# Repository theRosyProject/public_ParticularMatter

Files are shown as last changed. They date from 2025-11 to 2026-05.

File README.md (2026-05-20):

# ParticularMatter

ParticularMatter (https://particularmatter.org/) provides air quality monitoring devices built around ESP8266 and ESP32. It measures particulate matter (PM2.5 / PM10) using a PMS5003 sensor, air temperature, relative humidity and atmospheric pressure (T/RH/P) using the Bosch BME280, carbon dioxide (CO2) using the Senseair Sunrise sensor, and reports readings over MQTT.

This repository is the public release — it contains **firmware binaries**, **technical documentation**, and **presentation materials**. No source code is included (yet!).

**3D model (enclosure)** for the EPS8266 device mouting just the PMS5003 sensor:  [ParticulAIR-In 1 on MakerWorld](https://makerworld.com/en/models/1912756-particulair-in-1)

--> Models for the updated ESP32 version are under development.

---

## Repository structure

```
public_ParticularMatter/
├── builds/          # Pre-built firmware binaries and flashing instructions
│   ├── esp32/       # ESP32 firmware (current platform)
│   └── esp8266/     # ESP8266 firmware (legacy platform)
├── slides/          # Presentation and dissemination materials
├── tech-doc/        # Technical documentation (API, firmware internals, types, wiring)
└── LICENSE          # GPL v3
```

---

## Flashing the firmware

### ESP32

Pre-built binaries are in `builds/esp32/`. See [builds/esp32/README.md](builds/esp32/README.md) for full flashing instructions.

Quick start:

```bash
pip install esptool
esptool --chip esp32 --port PORT --baud 921600 write-flash 0x1000 builds/esp32/v1.4.0.bin
```

Replace `PORT` with your serial port (e.g. `/dev/tty.usbserial-0001` on macOS, `COM3` on Windows).

### ESP8266

... add, for compatibility with the legacy device and firmware.

---

## Documentation

Technical documentation lives in [`tech-doc/`](tech-doc/). This includes firmware internals, REST API reference, data types, enums, sensor details, and wiring guides.

---

## License

GPL v3 — see [LICENSE](LICENSE).

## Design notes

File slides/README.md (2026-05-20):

# Slides

Presentation and dissemination materials for the ParticularMatter project.

| File | Event | Date |
|---|---|---|
| `vincent-seminar-29-apr-2026.pdf` | Vincent's seminar at CNR - firmware  | Apr 29, 2026 |
| `ISGlobal_FDallo_pub.pdf` | Fede's seminar at ISGlobal - relevance | Nov 21, 2025 |
| `PM_LorenzoSeminar.pdf` | Lorenzo's seminar at CNR - app overview | Nov 3, 2025 |

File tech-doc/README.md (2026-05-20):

# Tech Doc

If you're looking for documentation on how this project works — firmware, API, types, or wiring — you're in the right place.

This folder covers everything on the technical side of the project. Browse the subfolders based on what you need:

- **`firmware-dev-particularmatter/`** — firmware internals, REST API endpoints, data types, enums, sensor info, and wiring references

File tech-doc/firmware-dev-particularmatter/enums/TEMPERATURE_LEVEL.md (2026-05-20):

# TEMPERATURE_LEVEL

Quality level enum for the `temperature` field in the [`/api/measurements/latest`](../api-docs/endpoints/measurements-latest.md) response.

Thresholds are based on the **ASHRAE 55** thermal comfort zone.

| Value | Color | °C |
| --- | --- | --- |
| `COLD` | 🔵 Blue | < 17 |
| `COOL` | 🟡 Yellow | 17 – 19 |
| `COMFORTABLE` | 🟢 Green | 20 – 26 |
| `WARM` | 🟡 Yellow | 27 – 30 |
| `HOT` | 🔴 Red | > 30 |

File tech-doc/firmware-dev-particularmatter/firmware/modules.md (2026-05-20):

# Firmware Modules

All reusable logic is organized into independent modules under `lib/`. Each module is a self-contained C++ class that is instantiated in `src/main.cpp` and wired together there.

---

## common/

Shared headers used across all modules. Not a class — these are just type and macro definitions.

| File | Description |
| --- | --- |
| `ConnectionState.h` | Enum for Wi-Fi connection states (`CONNECTED`, `CONNECTING`, etc.) |
| `NetworkState.h` | Enum for overall network/MQTT states |
| `Measurement.h` | Shared struct for sensor measurement payloads |
| `API_RESPONSE.h` | Helper functions for serializing uniform HTTP responses |
| `HELPER.h` | General utility macros |
| `LOGGING.h` | `LOGI` / `LOGE` logging macros (wraps `Serial.printf`) |

---

## ESPConfig

Persistent configuration stored in ESP32 NVS (Non-Volatile Storage). Survives reboots and factory resets can be triggered explicitly.

**Responsibilities:**
- Read / write device settings (Wi-Fi SSID/password, AP credentials, MQTT credentials, node ID)
- Provide a `getData()` accessor used by other modules

---

## WiFiManager

Manages the ESP32 Wi-Fi connection in STA mode. Operates asynchronously — call `maintain()` each loop iteration.

**Responsibilities:**
- Connect to a saved SSID
- Track `ConnectionState` (transitions: `DISCONNECTED` → `CONNECTING` → `CONNECTED` / `WRONG_PASSWORD` / `NO_NETWORK_FOUND`)
- Trigger network scan

---

## WebPortal

HTTP web server (port 80) that serves the LittleFS-hosted frontend and exposes the RESTful API. Operates asynchronously — call `maintain()` each loop iteration.

**Responsibilities:**
- Serve static files from LittleFS
- Register and handle all `/api/*` routes
- Drive the node registration flow (HTTPS call to backend, update `ESPConfig`)

See [`docs/api-docs/README.md`](../api-docs/README.md) for the full API reference.

---

## MQTTPublisher

MQTT client that publishes sensor data to the ParticularMatter platform. Operates asynchronously — call `maintain()` each loop iteration.

**Responsibilities:**
- Connect to the MQTT broker using credentials from `ESPConfig` (with 5–60 s exponential reconnect backoff)
- Each cycle, aggregate the latest snapshot from every sensor driver into a single `MeasurementData`
- Publish the aggregate as JSON to `measurements/{node_id}/{sensor_id}` when at least one sensor is valid (per-sensor validity → `null` for failed sensors). See [`docs/notes/mqtt.md`](../notes/mqtt.md) for the full payload schema.
- Forward each published `MeasurementData` to `XTSDStorageDriver::log()` for local CSV logging

---

## PMS5003Driver

Driver for the Plantower PMS5003 particulate matter sensor. Communicates over UART (RX pin 13).

**Responsibilities:**
- Parse binary data frames from the sensor
- Provide PM1.0, PM2.5, PM10 readings
- Non-blocking polling via `poll()`

---

## SenseAirCO2

Driver for the Senseair S8 CO2 sensor. Communicates over I2C.

**Responsibilities:**
- Request and parse CO2 concentration readings
- Non-blocking polling via `poll()`

---

## BME280Driver

Driver for the Bosch BME280 environmental sensor. Communicates over I2C.

**Responsibilities:**
- Read temperature, relative humidity, and barometric pressure
- Wraps the Adafruit BME280 library

---

## NEO6MGPSDriver

Driver for the u-blox NEO-6M GPS module. Communicates over UART1 (RX pin 14, TX pin 27, 9600 baud).

> ⚠️ Do **not** use GPIO 12 — it is the MTDI strapping pin, and GPS TX idles HIGH which forces the ESP32 to boot at 1.8 V flash voltage and bricks uploads.

**Responsibilities:**
- Parse NMEA sentences with TinyGPSPlus
- Provide latitude, longitude, altitude, HDOP, satellite count, and fix status
- Provide an ISO-8601 UTC `datetime` string when both GPS date and time are valid (used by MQTT payload and SD log filenames)

---

## XTSDStorageDriver

Driver for MicroSD card storage over VSPI (CS pin 33). Writes a CSV row per measurement, with daily file rotation and hot-plug support.

**Responsibilities:**
- Mount the SD card (`SD.begin()` with CARD_NONE detection); reinitialise every 3 s when removed
- Rotate log files daily: filename is `/YYYY-MM-DD_log.csv`, derived from the GPS UTC `datetime` of the row being written
- Use `/unknown_log.csv` as a fallback until GPS provides a valid time fix
- Lazily reopen the file as needed; on rotation, sniff the existing first line and append a header marker if the schema doesn't match (FAT cannot prepend)
- Detect I/O failures (card pulled mid-write) → `SD.end()` and schedule a 3 s reinit retry, so the next measurement triggers a fresh open + header check
- Write per-sensor invalid fields as **empty** values (not zeros), keeping partial readings unambiguous

**CSV columns:**

```
datetime,ts_ms,pm1,pm25,pm10,co2,temperature,humidity,pressure,lat,lng,altitude,hdop,satellites,gps_valid
```

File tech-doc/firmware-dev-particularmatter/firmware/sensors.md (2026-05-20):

# Sensors and Wiring

Board: Adafruit ESP32 Feather (HUZZAH32).

| Sensor | Interface | Pins |
| --- | --- | --- |
| PMS5003 | UART | RX = 13 |
| SenseAir S8 | I²C | SDA = 23, SCL = 22, address `0x68` |
| BME280 | I²C | SDA = 23, SCL = 22, address `0x76`/`0x77` |
| NEO-6M GPS  | UART | RX = 14, TX = 27 |
| MicroSD | SPI | CS = 33, SCK = 18, MOSI = 23, MISO = 19 |

## Power

- PMS5003: 5 V
- SenseAir S8: 5 V
- BME280: 3.3 V (or 5 V on Adafruit breakout)
- NEO-6M GPS: 3.3 V or 5 V
- MicroSD: 3.3 V

## Notes

- PMS5003 baud rate: 9600.
- NEO-6M baud rate: 9600.
- BME280 driver auto-detects between `0x76` and `0x77`.
- GPIO 12 is reserved (boot strapping pin) — don't use it.

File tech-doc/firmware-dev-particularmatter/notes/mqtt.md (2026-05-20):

# MQTT Format

## Topic

```
measurements/{node_id}/{sensor_id}
```

`node_id` and `sensor_id` come from pairing ([`POST /api/node/save`](../api-docs/endpoints/node-save.md)).

## Publish

- Interval: 5 seconds
- QoS: 0
- Retain: true
- Sent only after pairing is complete and at least one sensor has a valid reading.

## Payload

```json
{
  "measurement": {
    "pm1": 12,
    "pm25": 18,
    "pm10": 25,
    "co2": 493,
    "temperature": 24.50,
    "humidity": 55.20,
    "pressure": 1013.10,
    "gps": {
      "lat": 44.523474,
      "lng": 11.337641,
      "alt": 35.2,
      "hdop": 1.20,
      "sats": 7,
      "fix": 1
    }
  },
  "validity": { "pm": true, "co2": true, "env": true, "gps": true },
  "datetime": "2026-05-12T14:02:42Z",
  "ts_ms": 87234
}
```

## Fields

| Field | Type | Unit / Meaning |
| --- | --- | --- |
| `measurement.pm1` | `number \| null` | PM1.0, μg/m³ |
| `measurement.pm25` | `number \| null` | PM2.5, μg/m³ |
| `measurement.pm10` | `number \| null` | PM10, μg/m³ |
| `measurement.co2` | `number \| null` | CO₂, ppm |
| `measurement.temperature` | `number \| null` | °C |
| `measurement.humidity` | `number \| null` | %RH |
| `measurement.pressure` | `number \| null` | hPa |
| `measurement.gps.lat` | `number \| null` | latitude, degrees |
| `measurement.gps.lng` | `number \| null` | longitude, degrees |
| `measurement.gps.alt` | `number \| null` | altitude, m |
| `measurement.gps.hdop` | `number \| null` | horizontal dilution of precision |
| `measurement.gps.sats` | `number \| null` | satellites in fix |
| `measurement.gps.fix` | `0 \| 1` | 1 if GPS has a fix |
| `validity.pm` | `boolean` | PMS5003 reading valid |
| `validity.co2` | `boolean` | S8 reading valid |
| `validity.env` | `boolean` | BME280 reading valid |
| `validity.gps` | `boolean` | GPS has a fix |
| `datetime` | `string` | GPS UTC, `YYYY-MM-DDTHH:MM:SSZ` (empty if no time) |
| `ts_ms` | `number` | `millis()` since boot |

Invalid sensor fields are `null`. `ts_ms` is uptime in milliseconds, not epoch time.

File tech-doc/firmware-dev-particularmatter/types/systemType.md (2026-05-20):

# systemType

Type definition for the `systemStatus` field in `GET /api/system/status`.

| Field | Type | Description |
| --- | --- | --- |
| `firmwareName` | String | Always `"ParticularMatter-Node"` |
| `firmwareVersion` | String | e.g. `"v2.0.0"` |
| `macAddress` | String | ESP32 MAC address |
| `isPasswordChanged` | Boolean | `false` means the AP password is still at factory default |
| `firmwareSsid` | String | Current AP hotspot SSID |
| `allowedSkipInit` | Boolean | Status of allowing skip initialize the configuration |

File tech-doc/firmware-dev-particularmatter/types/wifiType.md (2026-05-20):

# wifiType

Type definition for the `wifiStatus` field in `GET /api/system/status`.

| Field | Type | Description |
| --- | --- | --- |
| `ssid` | String | Currently connected SSID; empty string when not connected |
| `ipAddress` | String | Device IP address in STA mode; empty string when not connected |
| `macAddress` | String | ESP32 MAC address |
| `rssi` | Number | Signal strength in dBm; `0` when not connected |
| `connectionState` | [CONNECTION_STATE](../enums/CONNECTION_STATE.md) | WiFi connection state |

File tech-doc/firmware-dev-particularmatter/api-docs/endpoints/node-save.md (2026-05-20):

# POST /api/node/save

Pairs the device with the ParticularMatter platform using a one-time key (OTK).

On success, the device receives MQTT credentials and begins publishing sensor data automatically. Poll [`GET /api/system/status`](./system-status.md) to track the `pairingState`.

> **Prerequisite:** The device must have an active WiFi connection (`connectionState === "CONNECTED"`) before calling this endpoint.

## Request

| Field | Value |
| --- | --- |
| URL | `/api/node/save` |
| Method | POST |
| Content-Type | application/json |
| Auth | None |

### Request Body

| Field | Type | Required | Description |
| --- | --- | --- | --- |
| `oneTimeKey` | String | Yes | Time-limited key generated by the ParticularMatter platform |

### Request Example

```json
{
  "oneTimeKey": "OTK-a1b2c3d4e5f6"
}
```

## Response (`data`)

```json
{}
```

## Pairing State Tracking

Pairing is asynchronous. After calling this endpoint, poll `GET /api/system/status` and observe `pairingState`:

| pairingState | Description |
| --- | --- |
| `REGISTERING` | Device is executing the pairing request in the background |
| `REGISTERED` | Pairing successful |
| `INVALID_KEY` | Server returned 400 / 401 / 403 (key invalid or expired) |
| `NETWORK_ERROR` | Server unreachable, timeout, or TLS failure |

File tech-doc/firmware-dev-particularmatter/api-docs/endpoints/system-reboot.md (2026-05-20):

# POST /api/system/reboot

Triggers an ESP32 reboot.

## Request

| Field | Value |
| --- | --- |
| URL | `/api/system/reboot` |
| Method | POST |
| Content-Type | application/json |
| Auth | None |

### Request Body

None.

## Response (`data`)

```json
{}
```

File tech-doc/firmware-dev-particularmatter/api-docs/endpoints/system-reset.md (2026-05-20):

# POST /api/system/reset

Factory resets the ESP32 by clearing all saved settings. The device reboots automatically after the reset completes.

## Request

| Field | Value |
| --- | --- |
| URL | `/api/system/reset` |
| Method | POST |
| Content-Type | application/json |
| Auth | None |

### Request Body

None.

## Response (`data`)

```json
{}
```

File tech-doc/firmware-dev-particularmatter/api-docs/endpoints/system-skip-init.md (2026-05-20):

# POST /api/system/skip-init

Sets `allowedSkipInit` to `true` on the ESP32, allowing the device to skip the initialization step on next boot.

## Request

| Field | Value |
| --- | --- |
| URL | `/api/system/skip-init` |
| Method | POST |
| Content-Type | application/json |
| Auth | None |

### Request Body

None.

## Response (`data`)

```json
{}
```

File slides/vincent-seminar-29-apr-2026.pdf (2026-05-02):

ISP-CNR – Feng Chia University Students' Internship – 29 April 2026

# User-friendly ESP32 firmware application to simplify network configuration for open-source IoT devices

Meng Xian Yang
& Federico Dallo

# The problem – Needs

- Necessary to build new tools (models and data) to estimate
- Indoor exposure to air pollution
- Main causes (activities, building factors, infiltration, etc)
- The results will be used
- to inform target stakeholders (municipalities, building sector, environmental agencies, …)
- to develop specific intervention (e.g., new ERF, greening, enhance air filtration in buildings, …)
→ EU funded project healthRiskADAPT | WP leader ISP-CNR

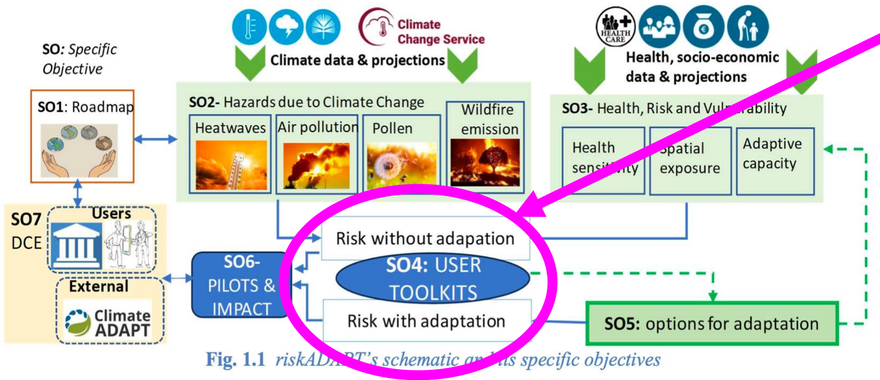
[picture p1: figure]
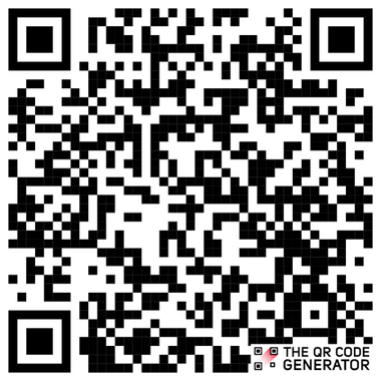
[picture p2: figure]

# The problem – Existing Solution

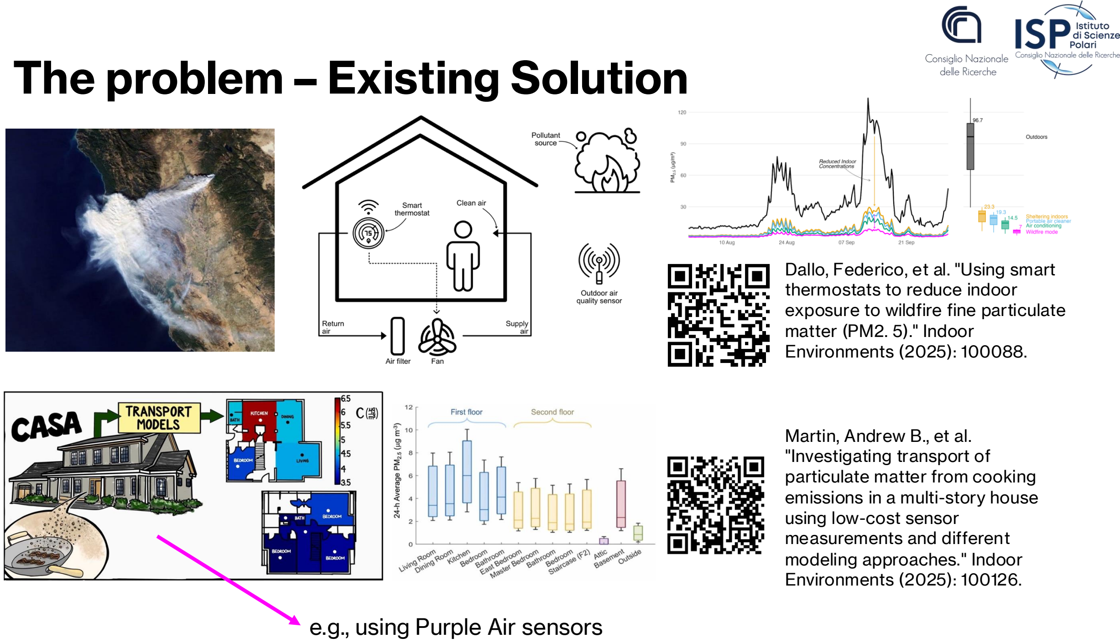
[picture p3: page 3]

Dallo, Federico, et al. "Using smart thermostats to reduce indoor exposure to wildfire fine particulate matter (PM2. 5)." Indoor
Environments (2025): 100088.

Martin, Andrew B., et al.
"Investigating transport of particulate matter from cooking emissions in a multi-story house using low-cost sensor
measurements and different modeling approaches." Indoor Environments (2025): 100126.

e.g., using Purple Air sensors

# Locations & Sensors Management

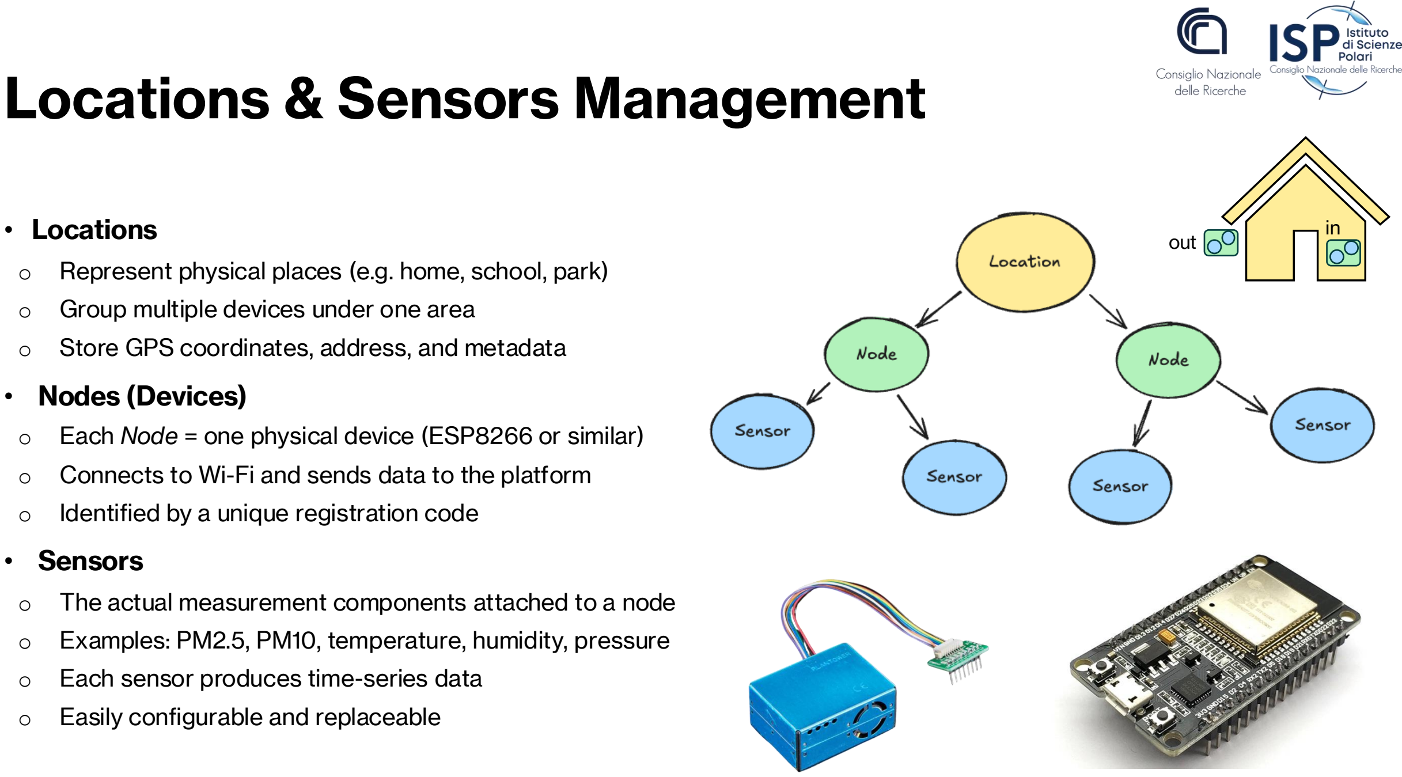
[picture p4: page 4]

- Locations
- Represent physical places (e.g. home, school, park)
- Group multiple devices under one area
- Store GPS coordinates, address, and metadata
- Nodes (Devices)
- Each Node = one physical device (ESP8266 or similar)
- Connects to Wi-Fi and sends data to the platform
- Identified by a unique registration code
- Sensors
- The actual measurement components attached to a node
- Examples: PM2.5, PM10, temperature, humidity, pressure
- Each sensor produces time-series data
- Easily configurable and replaceable

out

in

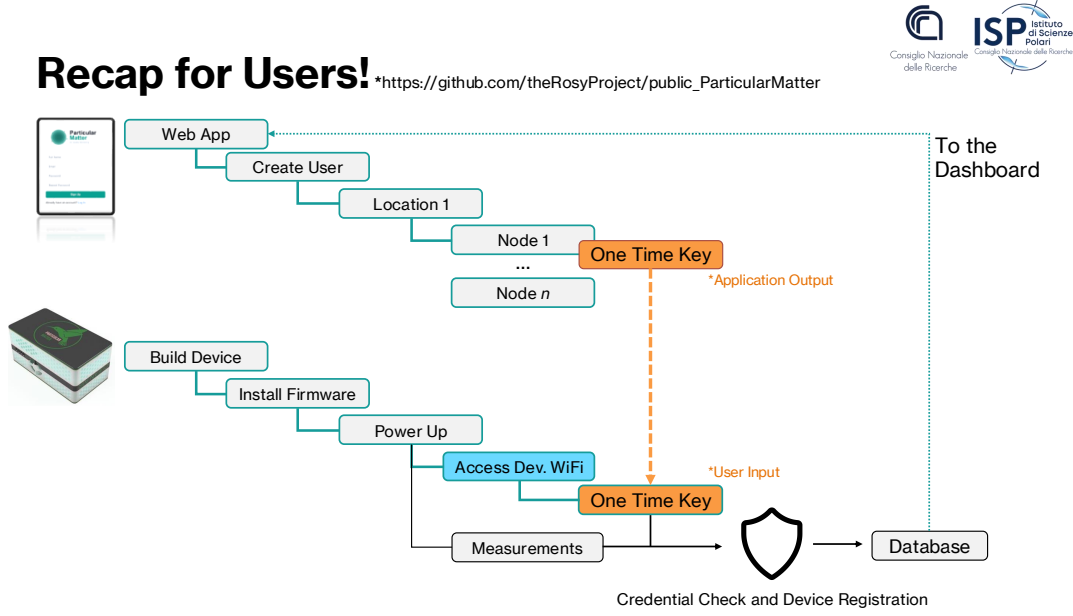
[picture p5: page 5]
Web App; Create User; Location 1; Node 1; Node n; Build Device; Install Firmware; Power Up; Measurements; Database; To the Dashboard; *Application Output; *User Input

Recap for Users! *https://github.com/theRosyProject/public_ParticularMatter

One Time Key

Access Dev. WiFi

Credential Check and Device Registration

ISP-CNR – Feng Chia University Students' Internship – 29 April 2026

# User-friendly ESP32 firmware application to simplify network configuration for open-source IoT devices

Meng Xian Yang
& Federico Dallo

# Introduction – Meng Xian Yang (Vincent)

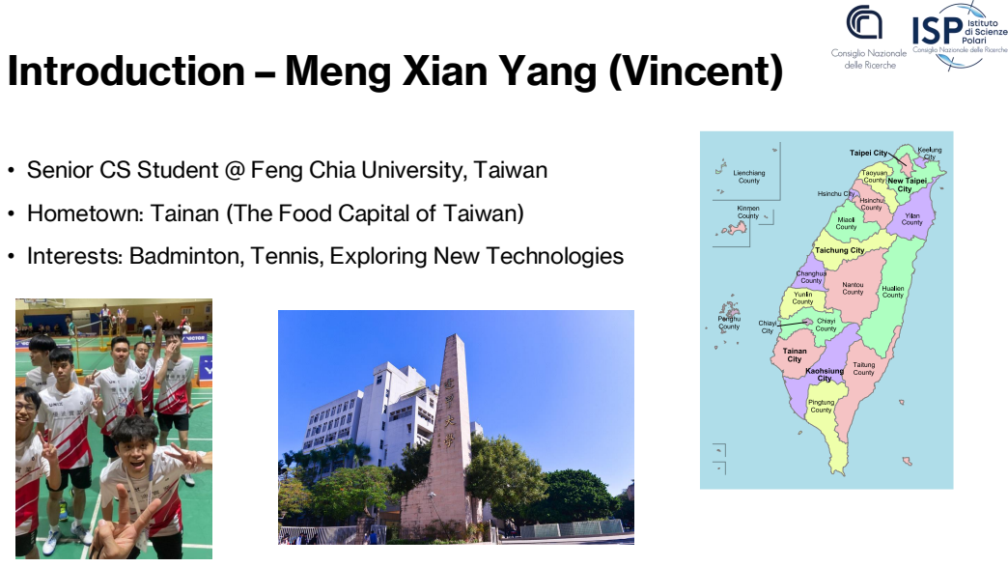
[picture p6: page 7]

• Senior CS Student @ Feng Chia University, Taiwan

• Hometown: Tainan (The Food Capital of Taiwan)

• Interests: Badminton, Tennis, Exploring New Technologies

# My Tech Stack & Background

- 3 Years of Software Development | 1 Year of AI Engineering
- Software Engineering
- Focus: Full-stack Development · System Integration · Cloud Deployment
- Tech Stack: Node.js, NestJS, React, PostgreSQL, Firebase, Docker, GCP, etc.
- AI & Computer Vision
- Focus: Object Detection · Multi-Object Tracking · Model Training
- YOLO, SAM, DeepSORT, etc.

# Earlier Work: 360° Badminton Highlight System

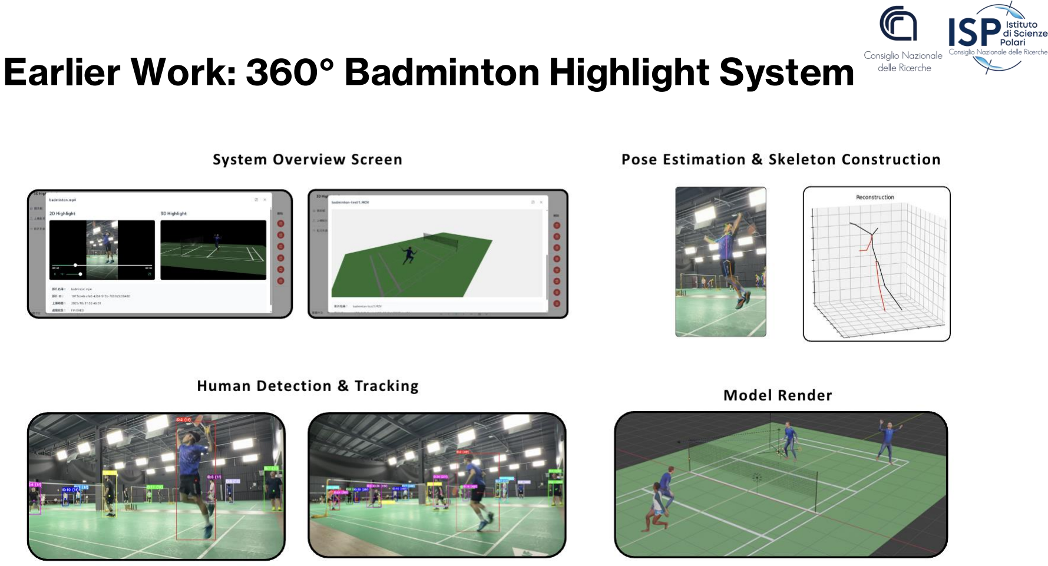
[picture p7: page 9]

# CNR: World-Class Research in a Historic City

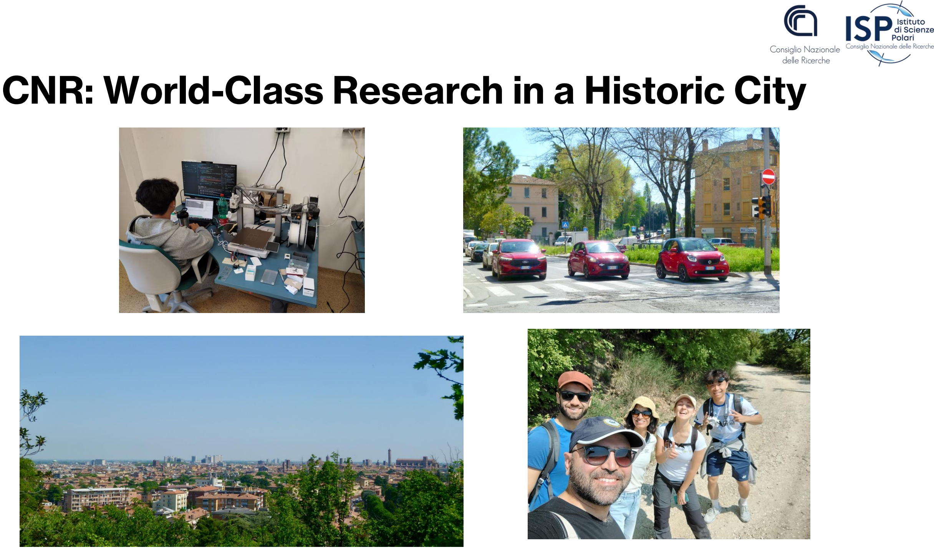
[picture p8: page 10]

# Particular Matter Framework

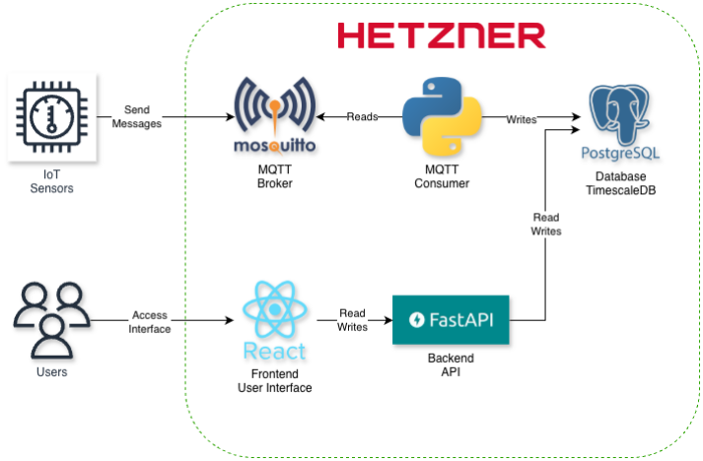
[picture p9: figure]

System Architecture Overview

# The solution – what?

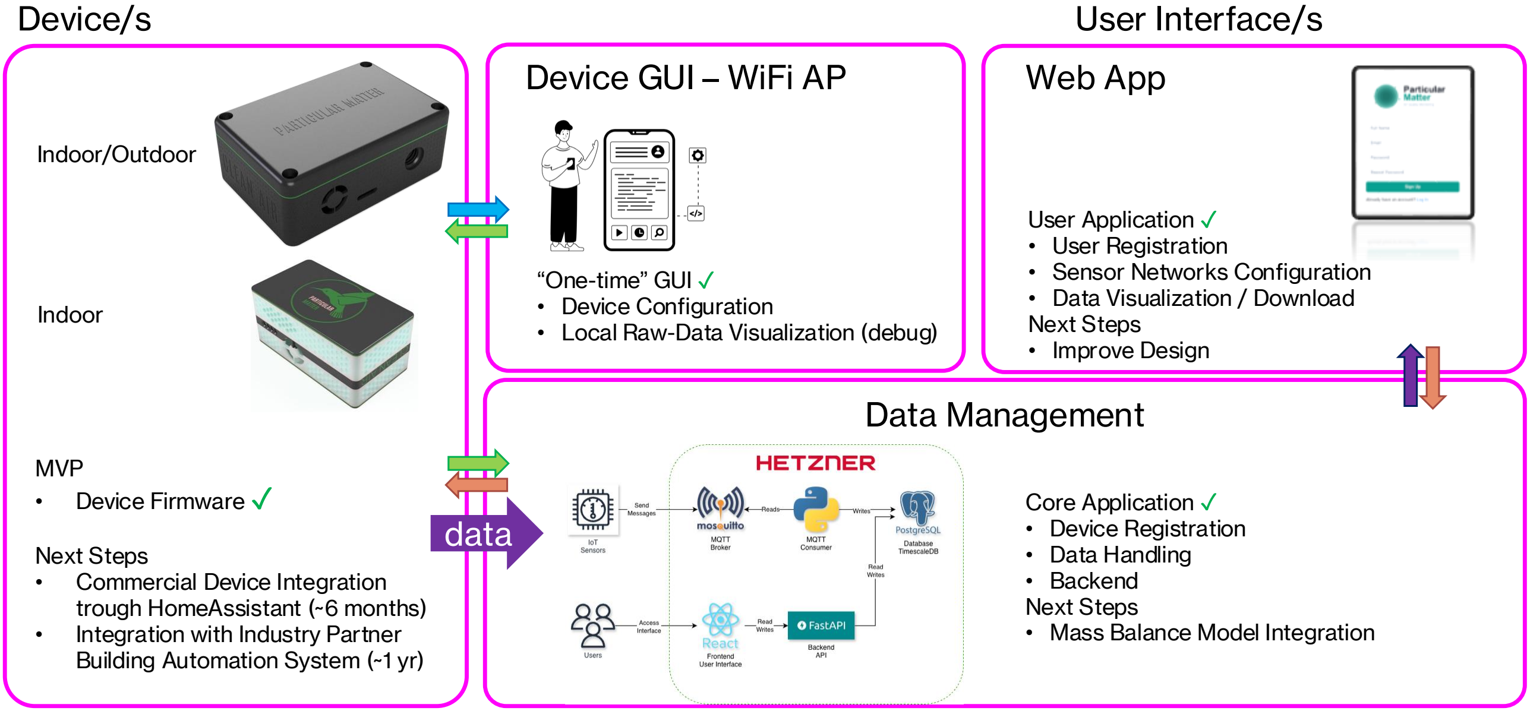
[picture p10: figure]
Device/s; Data Management; User Interface/s; Indoor/Outdoor; Indoor; MVP • Device Firmware ✓; Next Steps • Commercial Device Integration trough HomeAssistant (~6 months) • Integration with Industry Partner Building Automation System (~1 yr); Device GUI – WiFi AP; Web App; “One-time” GUI ✓ • Device Configuration • Local Raw-Data Visualization (debug); User Application ✓ • User Registration • Sensor Networks Configuration • Data Visualization / Download Next Steps • Improve Design; Core Application ✓ • Device Registration • Data Handling • Backend Next Steps • Mass Balance Model Integration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

# DIY Device – Registration

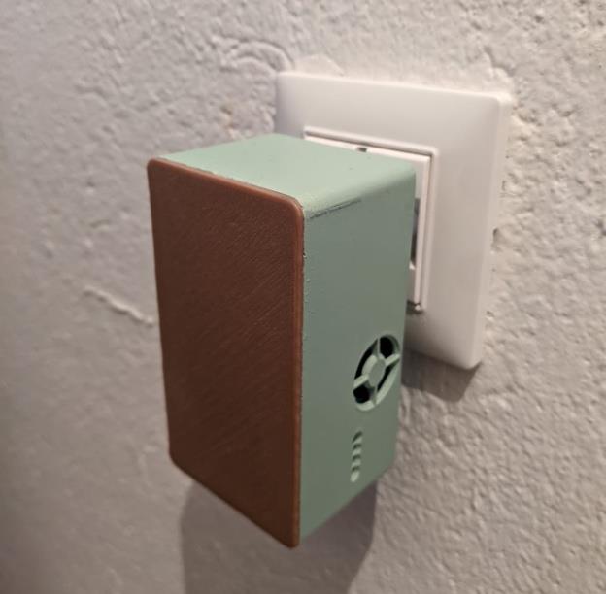
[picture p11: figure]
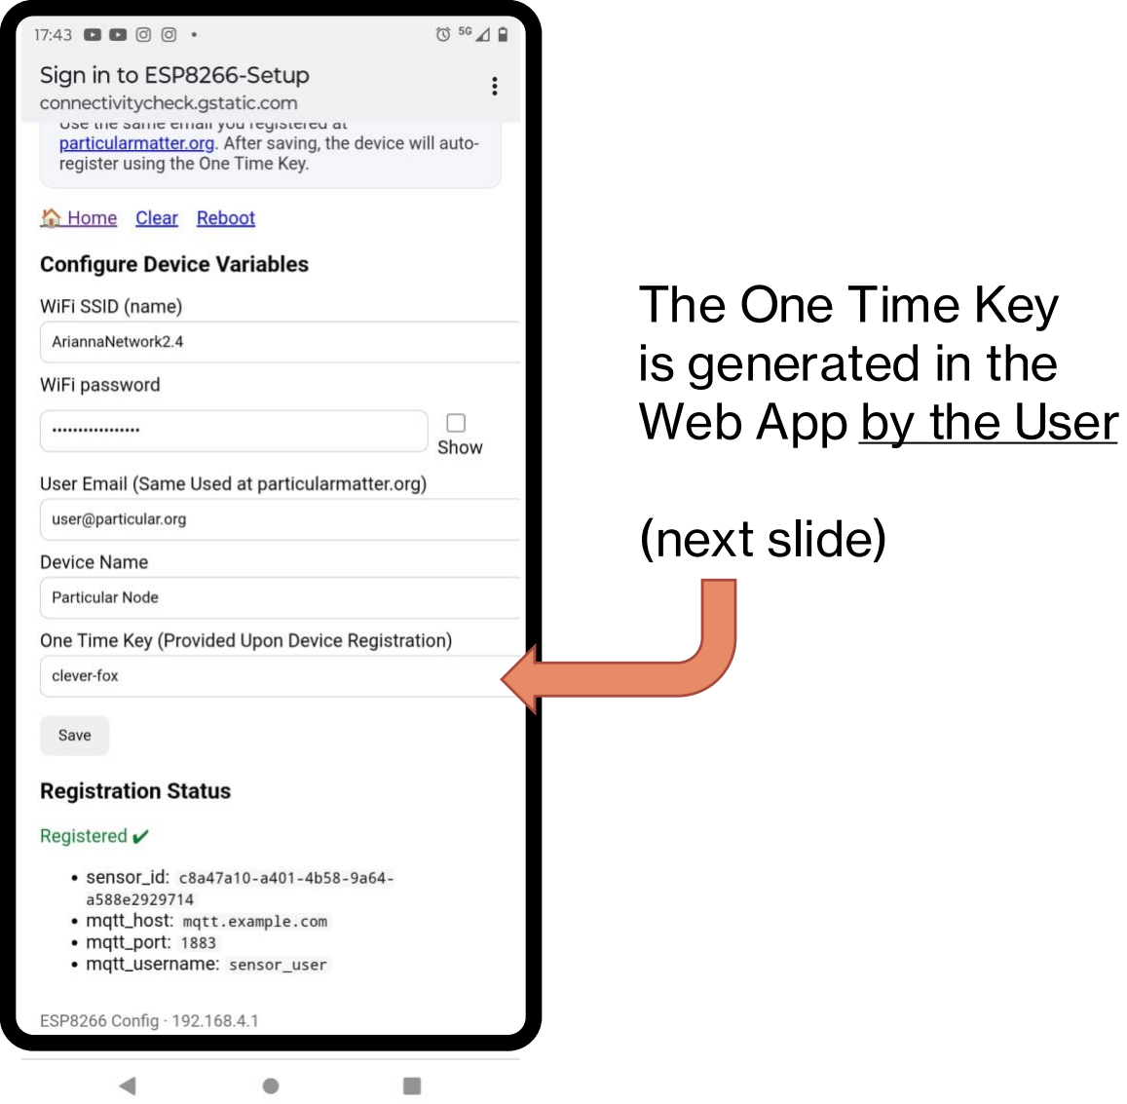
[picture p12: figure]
The One Time Key is generated in the Web App by the User; (next slide)

1) Plug the device to connect
to the WiFi Access Point:

SSID: ParticularMatterDevice-Setup PWD: particularmatter

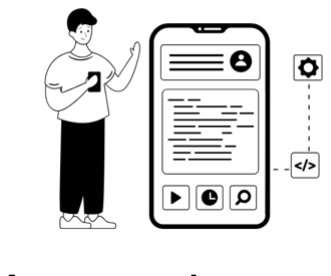
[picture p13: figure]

Automatic
Redirect
(e.g., like
airports’ captive
portals)

# WebApp – Sensor Networks Configuration

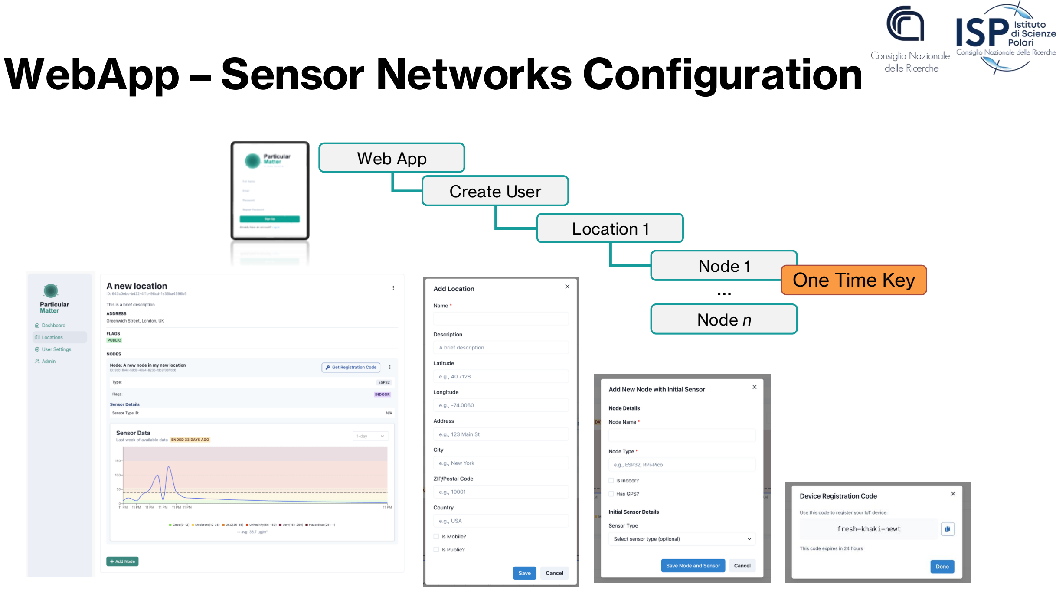
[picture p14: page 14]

Web App

Create User

Location 1

Node 1

Node n

…

One Time Key

# From Prototype to Open Source

Current Bottlenecks:

- Software: Monolithic design (hardcoded in main.cpp) & steep learning curve.
- Hardware: Legacy ESP8266 limits performance and lacks pins for future expansions.

The Upgrade Vision (healthRiskADAPT):

- Software Open-Source: Build a modular, user-friendly repository for non-CS researchers.
- Hardware Migration: Upgrade to the ESP32 microcontroller.
- Scalable Architecture: Redesign the wiring and power distribution to support future sensors (e.g., GPS, Temp., Relative Humidity, Pressure, CO2, CH4, ...).

# The Solution Outline

- System Modularization
- Frontend-Backend Decoupling
- API-First Development
- CI/CD Pipeline (Continues Integration / Continues Deployment)

# New Firmware Architecture

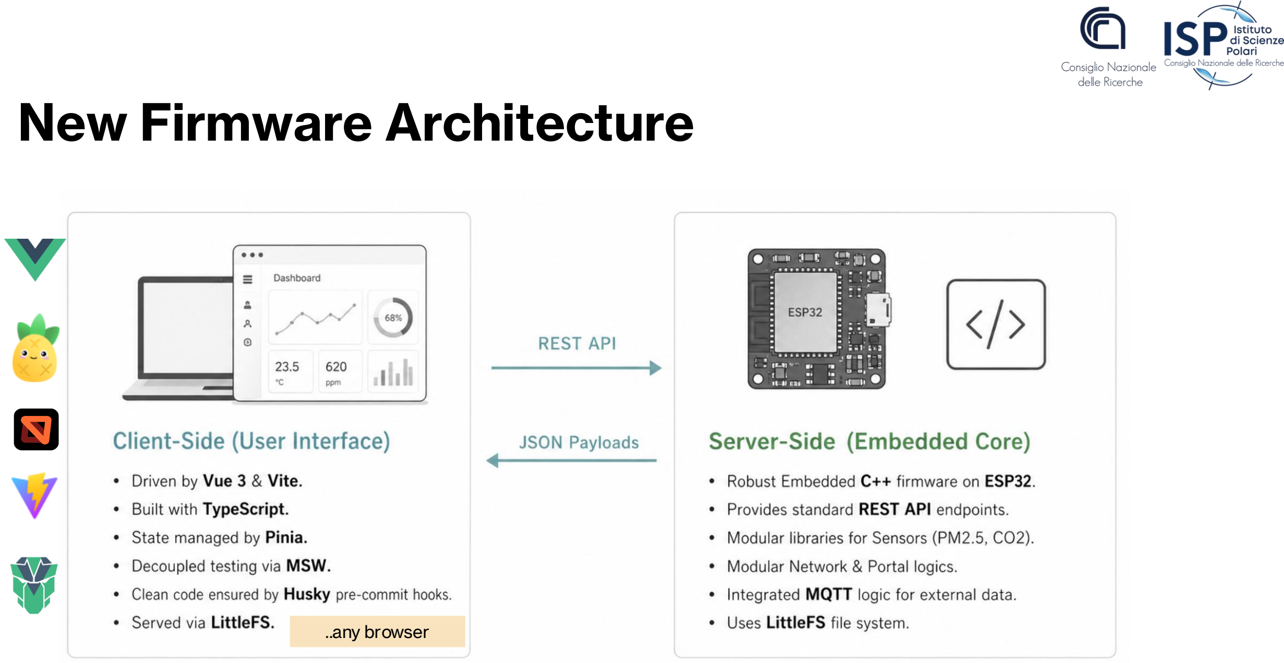
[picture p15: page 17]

..any browser

# System Modularization

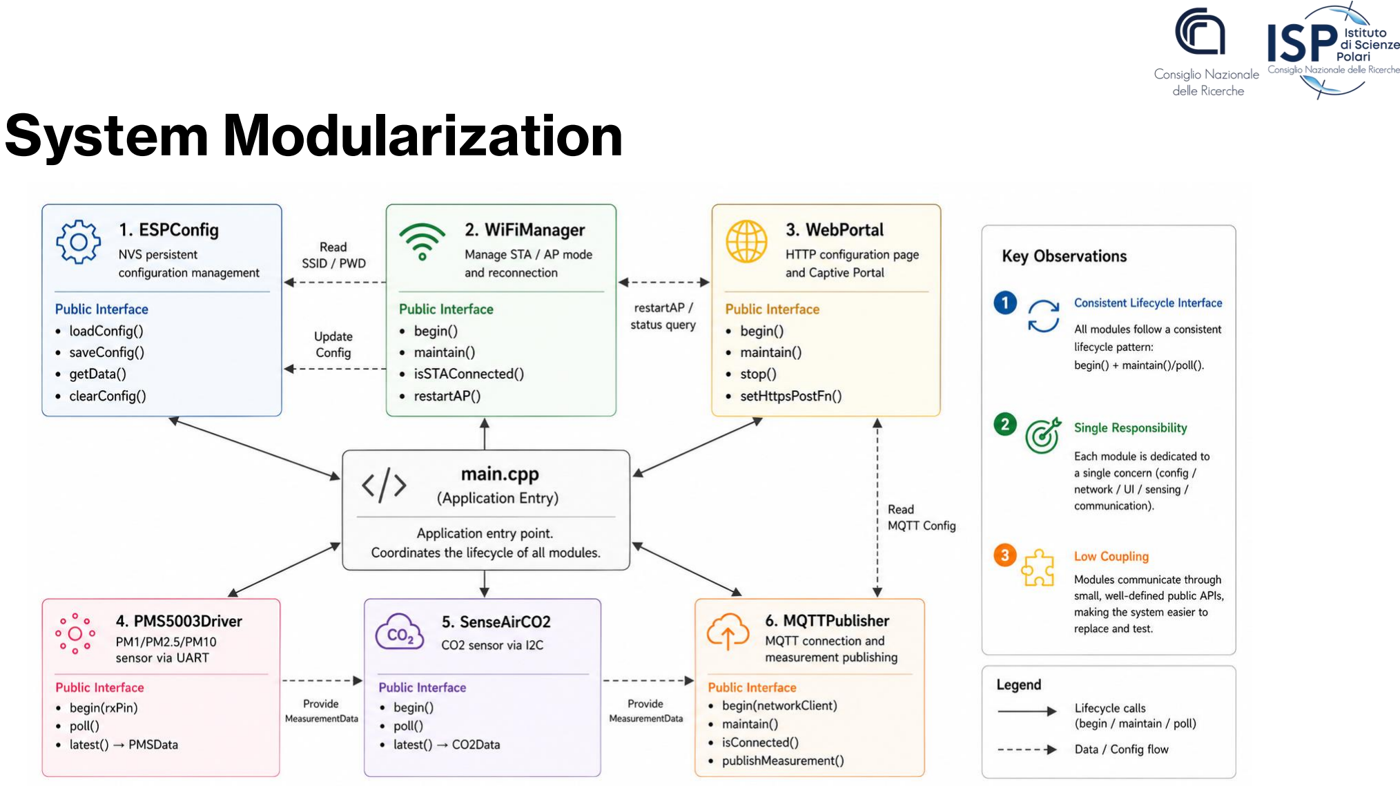
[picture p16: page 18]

# The Core State Machine

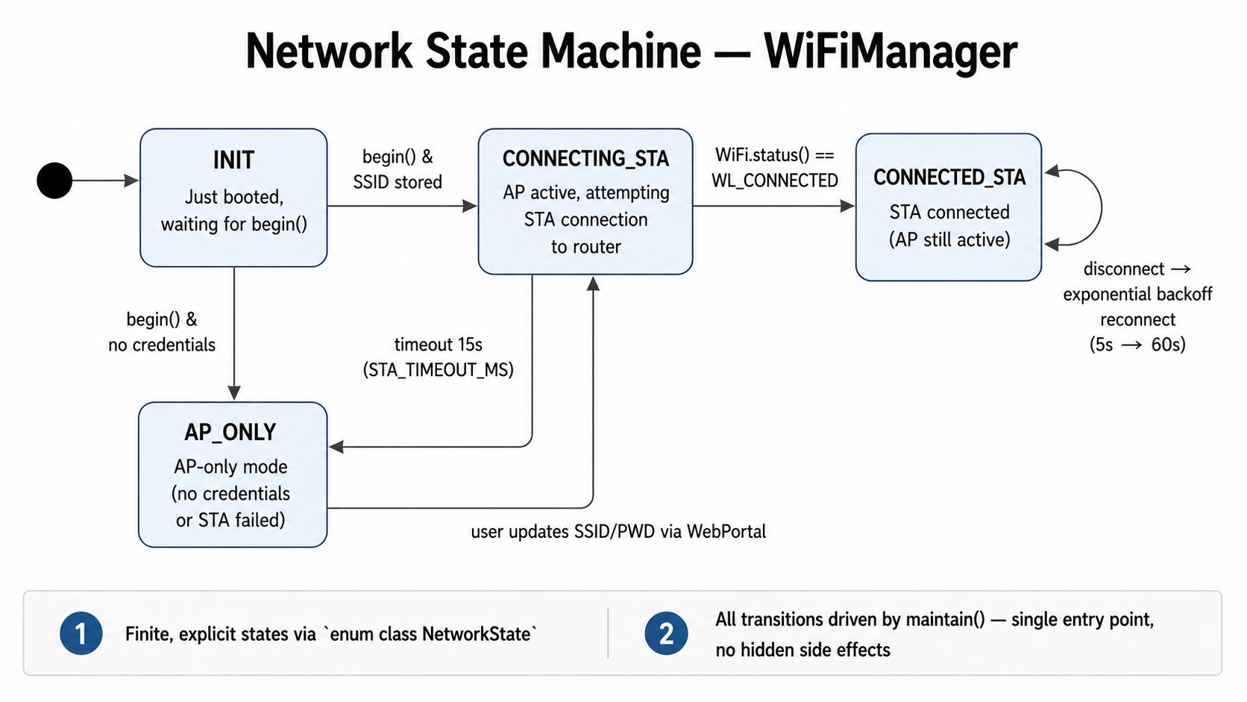
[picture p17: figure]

# The Core State Machine

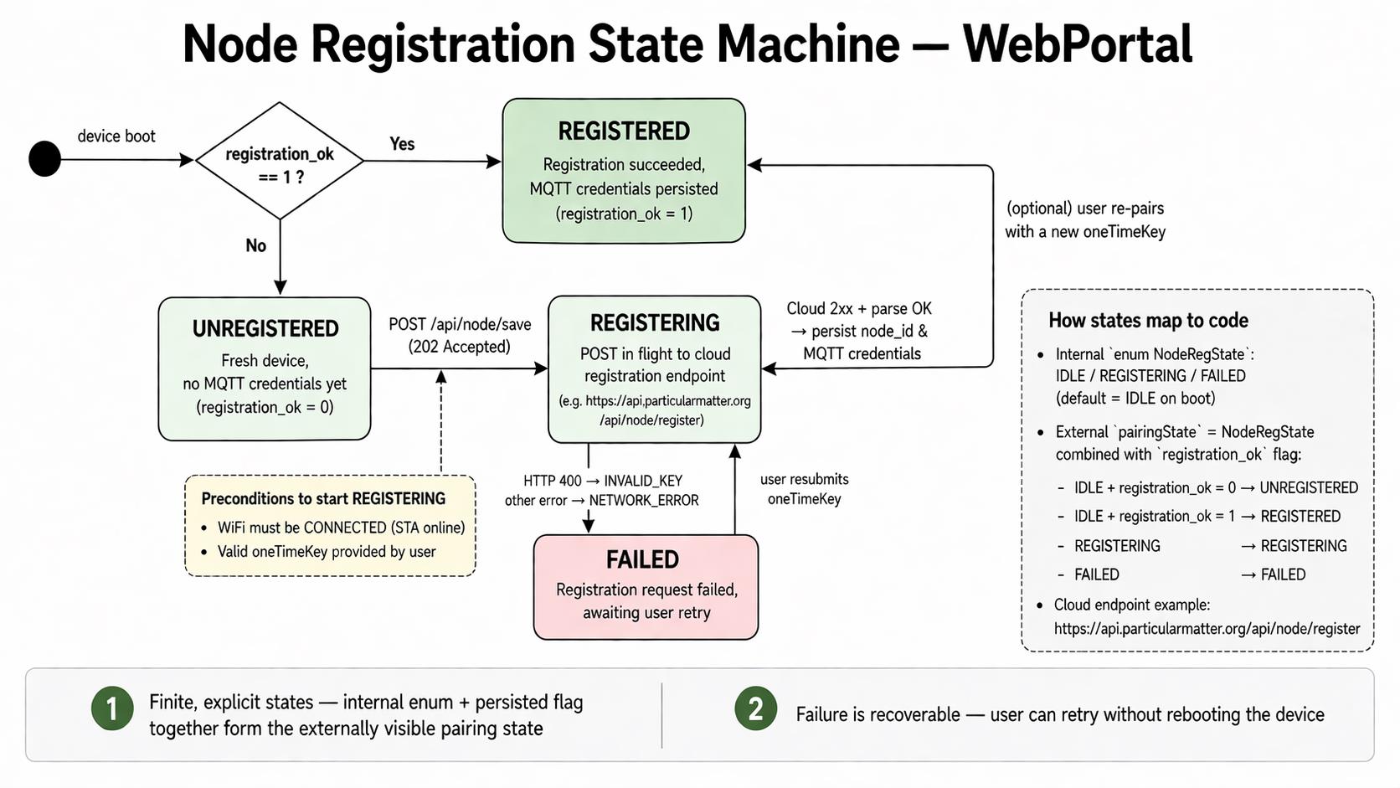
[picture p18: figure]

# Frontend-Backend Decoupling

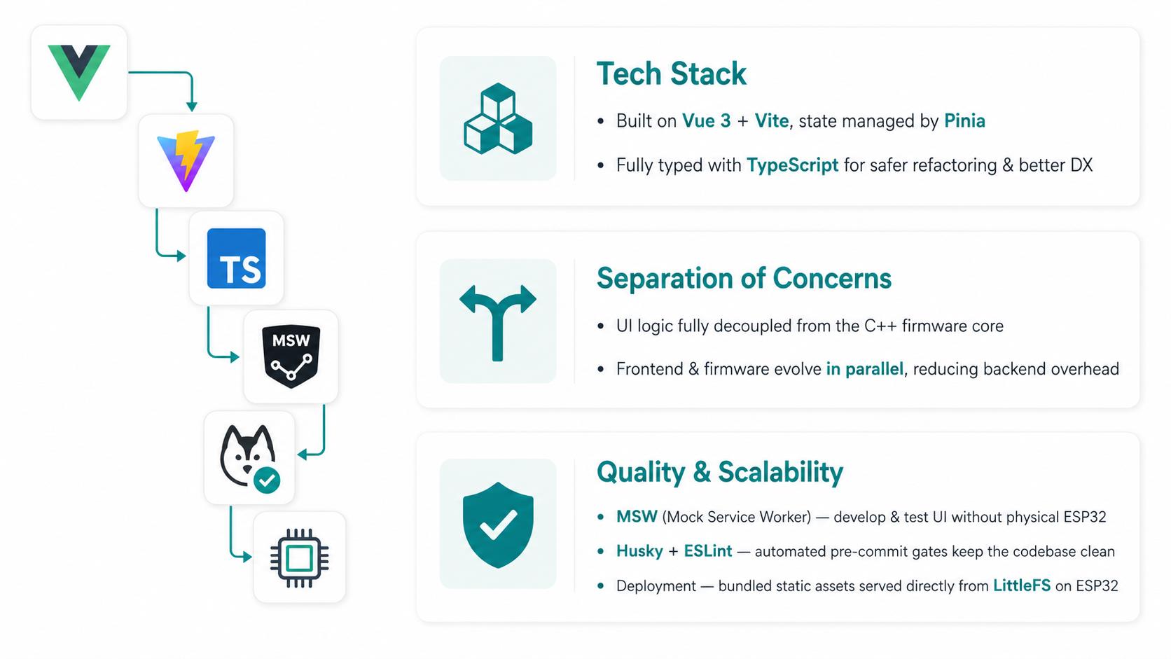
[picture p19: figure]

# Initialization

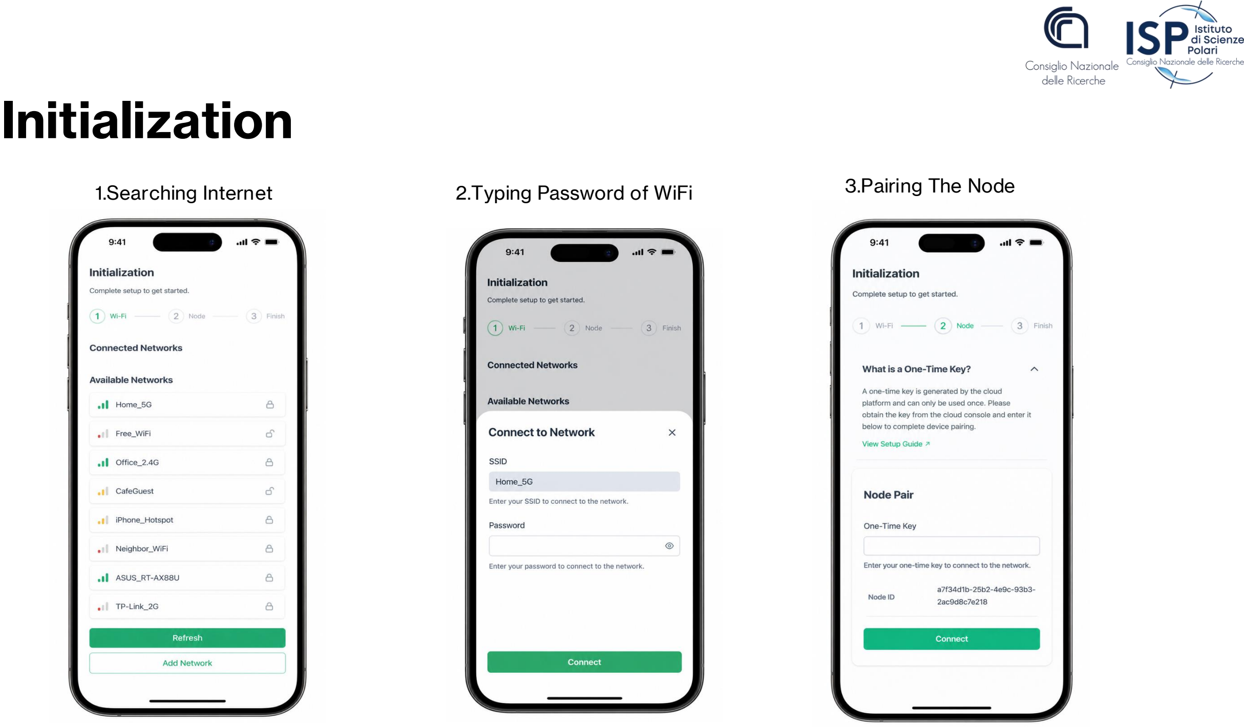
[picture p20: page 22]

1.Searching Internet | 2.Typing Password of WiFi | 3.Pairing The Node

# Real-Time Monitoring

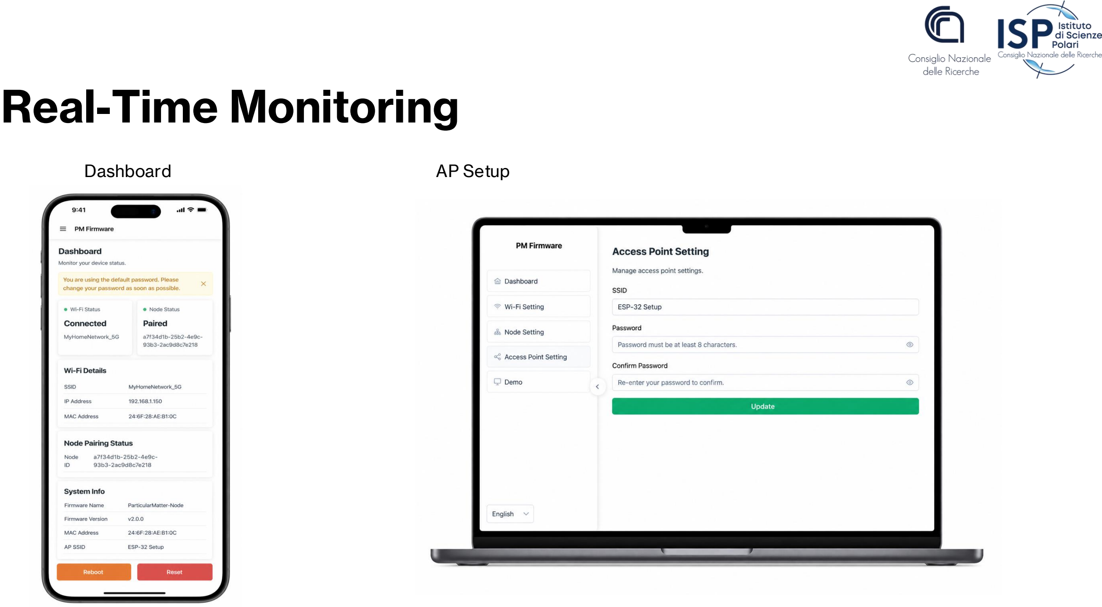
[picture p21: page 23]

Dashboard | AP Setup

# The API-First Cycle

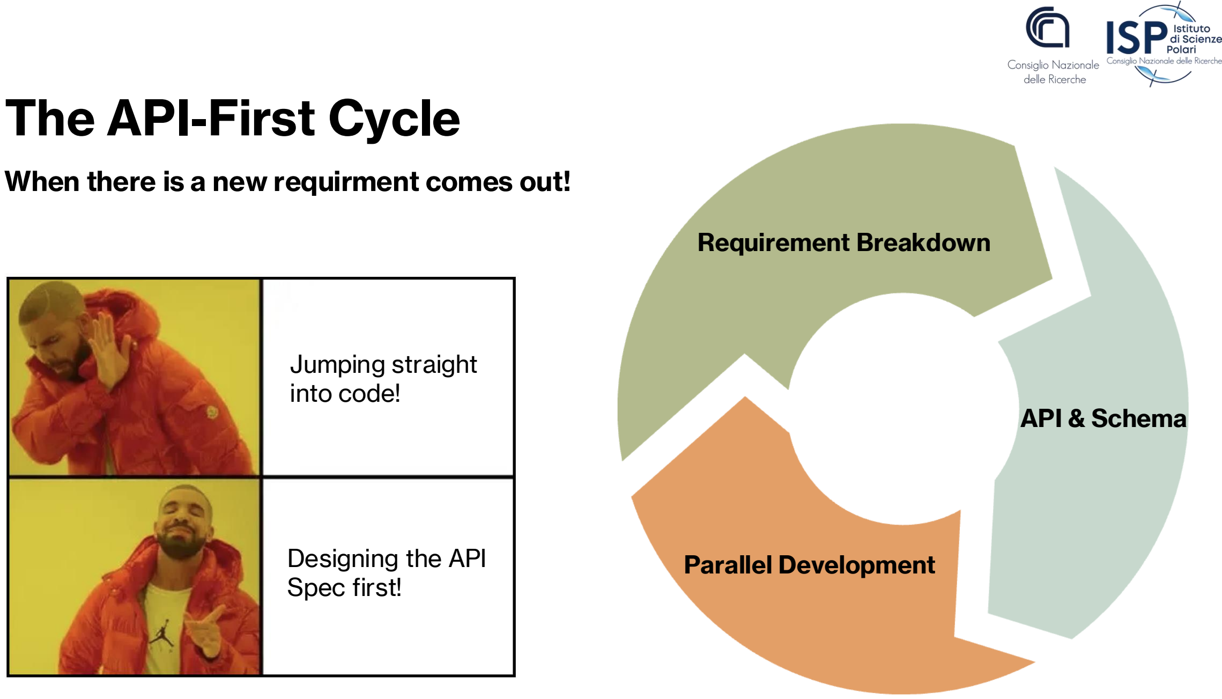
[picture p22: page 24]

When there is a new requirment comes out!

Jumping straight
into code!

Designing the API
Spec first!

API & Schema

Requirement Breakdown

Parallel Development

# CI/CD & Automated Pipeline

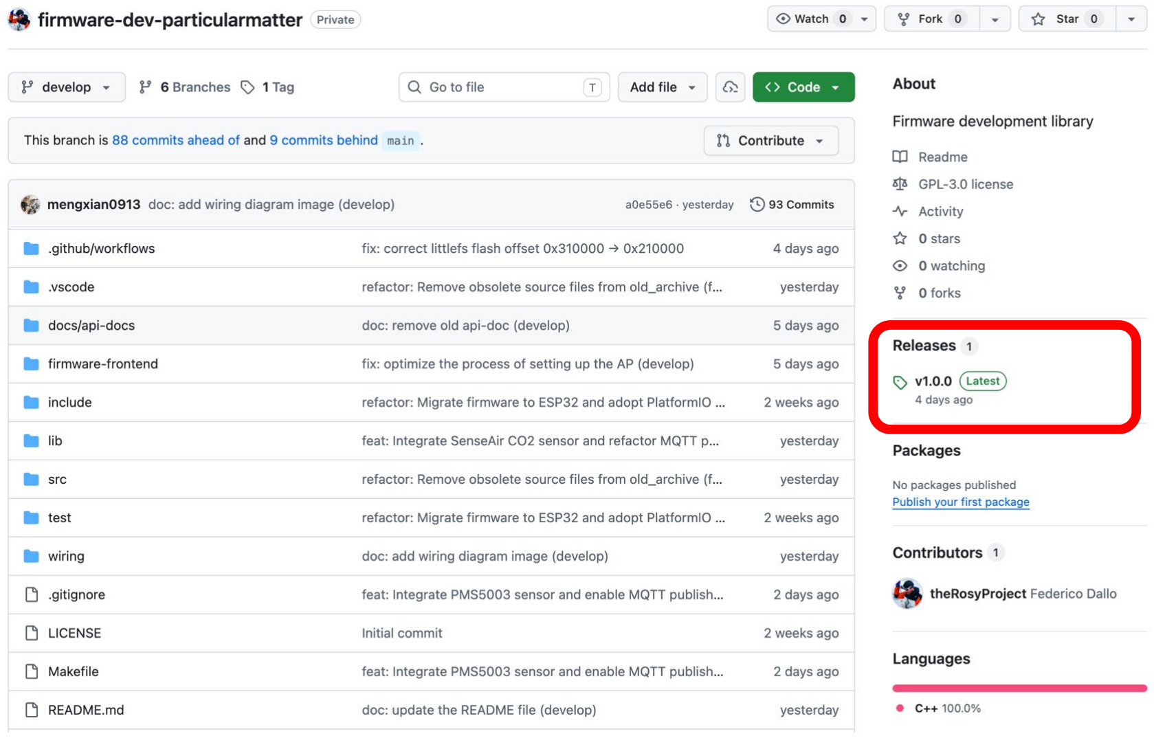
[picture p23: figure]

# What is next step ?

### 1. Hardware Ecosystem Expansion

- Integrating additional modules (e.g., GPS, SD Card storage).

### 2. Open-Source Readiness

- Finalizing comprehensive GitHub documentation (README, API Wiki) for future researchers.

### 3. Field Deployment

- Moving from the lab to real-world testing.

# Thank You

email: mengxian0913@gmail.com

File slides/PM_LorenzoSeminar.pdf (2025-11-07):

Polar Science Talks, Research and Future Perspectives, Nov 7, 2025

# User-Friendly IoT Infrastructure for Deploying Wireless Sensor Networks in Outdoor and Indoor Monitoring

Lorenzo Tenti
Alessandro B. Palo
& Federico Dallo

# Introduction – Lorenzo Tenti (PhD)

Data Engineer · MLOps Specialist · Researcher

- Background in theoretical and computational chemistry (PhD, University of Ferrara)
- Moved from science to data engineering and applied machine learning
- Consultant designing and deploying production-grade, data-intensive systems that leverage machine learning and AI
- Postdoctoral fellow at ISP-CNR (MISO project, environmental and health data)
- Many overlaps with the healthRiskADAPT project
- Interested in exploring and applying innovative technologies that connect IoT, data, and machine learning

# Introduction – IoT

The Internet of Things (IoT) refers to a network of interconnected devices - such as sensors, appliances, vehicles, and machines - that can collect, exchange, and act on data through the internet. These devices are often equipped with sensors and communication capabilities, allowing them to monitor their environment, share information in real time, and be controlled remotely.

In essence, IoT bridges the physical and digital worlds, enabling smarter systems in areas such as environmental monitoring, healthcare, transportation, and home automation.

International Telecommunication Union (ITU). (2012). Overview of the Internet of Things. ITU-T Y.2060. Geneva: ITU. https://www.itu.int/rec/T-REC-Y.2060-201206-I/en

# Introduction – IoT Trends

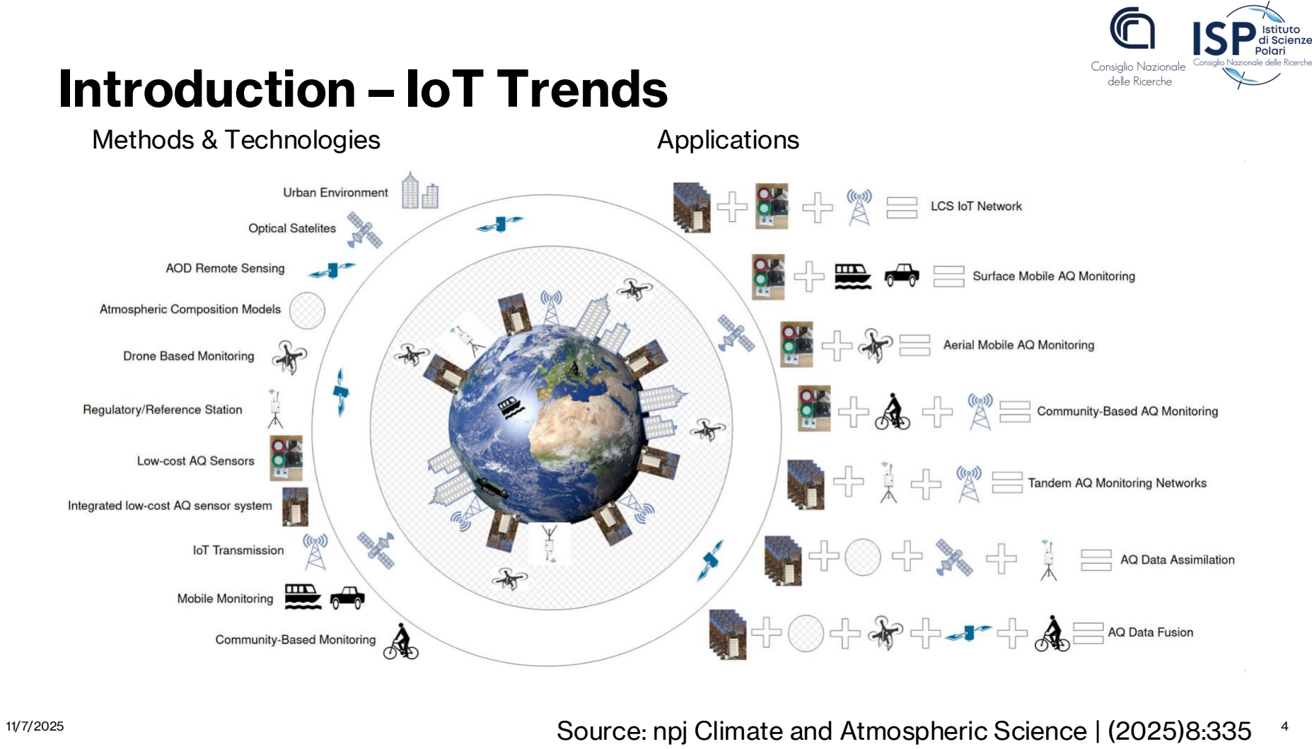
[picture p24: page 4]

11/7/2025
4
Methods & Technologies | Applications
Source: npj Climate and Atmospheric Science | (2025)8:335

# Introduction – Why Air Quality (AQ)?

11/7/2025
5

1
IHME, Institute for Health Metrics and Evaluation
2 WHO, Total burden of disease from household and ambient air pollution
- Air pollution is the second leading risk factor for death globally¹ after high blood pressure
- Air pollution is linked to up to 90% of the disease burden from noncommunicable diseases, including heart disease, stroke, diabetes, lung cancer, and chronic obstructive pulmonary disease ²
- 6.7 million premature deaths in 2019 from exposure to ambient and household air pollution ²
- 2.1 billion people primarily rely on polluting fuels and technologies for cooking in 2023 ²
- 99% of the world’s population live in places where air pollution levels exceed WHO guideline limits ²

# Introduction – IoT AQ Examples


11/7/2025

6 Source: npj Climate and Atmospheric Science | (2025)8:335

> 30k users, quite
some interest!

Private

Non-Profit

# The problem – Indoors

- 90% of exposure to air pollution happens indoors
- Infiltration of outdoor air pollution
- Indoor activities (e.g., cooking, cleaning, … smoking)
- The indoor environment is VERY complex
- Building type (age, size, insulation, equipement installed, …)
- Occupants (number, age, behaviour, …)
- Location (climate, sources, built environments, …)
- Indoor and outdoor sources of air pollution
- Human Behaviour and Gender Dimension
- …

https://iaq.ucdavis.edu/
--> great video series

Exposure to Air Pollution: Largely Unknown, with Health Impacts Accounting for Only 10% of time spent outdoors → We need tools to measure indoor spaces

# The problem – Needs

- Necessary to build new tools (models and data) to estimate
- Indoor exposure to air pollution
- Main causes (activities, building factors, infiltration, etc)
- The results will be used
- to inform target stakeholders (municipalities, building sector, environmental agencies, …)
- to develop specific intervention (e.g., new ERF, greening, enhance air filtration in buildings, …)
→ EU funded project healthRiskADAPT | WP leader ISP-CNR


# The problem – Existing Solution


Dallo, Federico, et al. "Using smart thermostats to reduce indoor exposure to wildfire fine particulate matter (PM2. 5)." Indoor
Environments (2025): 100088.

Martin, Andrew B., et al.
"Investigating transport of particulate matter from cooking emissions in a multi-story house using low-cost sensor
measurements and different modeling approaches." Indoor Environments (2025): 100126.

e.g., using Purple Air sensors

# The problem – why so relevant?

- Commercial and ‘Open-Source’ monitoring devices already exist…
- Purple Air
- Sensor.Community

→ Lack of IoT application/framework to be focused on Indoor Environments

Public Health, Building Control and also Education*

*Why this is also relevant for remote areas?
Cities: ~4% of EU landcover
- 75% population lives
- Consumption > 65% of global energy
- 70% CO2 emissions
→ Environmental co-benefits are huge EU Missions:
- Climate Resilience
- Climate-Neutral Cities


FIGURE 2-6 Output from a NASA model showing the different sources of particulate matter. Red = dust, blue = sea salt, green = smoke, and white = sulfate. SOURCE: Farmer slide 3 (NASA Center for Climate Simulation at Goddard Space Flight Center).

National Academies of Sciences, Engineering, and Medicine. 2022. Indoor Exposure to Fine Particulate Matter and Practical Mitigation Approaches: Proceedings of a Workshop. Washington, DC: The National Academies Press. https://doi.org/10.17226/26331.

# The solution – what?

Device/s; Data Management; User Interface/s; Indoor/Outdoor; Indoor; MVP • Device Firmware ✓; Next Steps • Commercial Device Integration trough HomeAssistant (~6 months) • Integration with Industry Partner Building Automation System (~1 yr); Device GUI – WiFi AP; Web App; “One-time” GUI ✓ • Device Configuration • Local Raw-Data Visualization (debug); User Application ✓ • User Registration • Sensor Networks Configuration • Data Visualization / Download Next Steps • Improve Design; Core Application ✓ • Device Registration • Data Handling • Backend Next Steps • Mass Balance Model Integration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

# DIY Device – Hardware


Download STL File for 3D printer: https://makerworld.com/en/models/1912756-particulair-in-1

Building Materials:
- 3D printed enclosure
- ESP microcontroller
- Plantower PMS5003
- bme280 T-RH-P
- micro-USB power supply

→ soon: Senseair CO2 sensor

STL file

# DIY Device – Firmware


1) 2) GoTo: https://web.esphome.io/

*the firmware is a file that contains the instructions for the
microcontroller

*No need to
Install any
Software

Download “firmware.bin” for ESP8266: https://github.com/.../src/build/esp8266/firmware.bin (https://github.com/theRosyProject/public_ParticularMatter/blob/main/src/build/esp8266/firmware.bin)

# DIY Device – Registration

The One Time Key is generated in the Web App by the User; (next slide)

1) Plug the device to connect
to the WiFi Access Point:

SSID: ParticularMatterDevice-Setup PWD: particularmatter

Automatic
Redirect
(e.g., like
airports’ captive
portals)

# WebApp – Sensor Networks Configuration

Web App

Create User

Location 1

Node 1

Node n

…

One Time Key

# System Overview


Three main parts working together:

- Edge Layer (IoT sensors)
- Data measurement
- Data collection
- Platform Layer
- Data processing
- Mass Balance Model (e.g., I/O ratio)
- Storage
- User Layer (via web interface)
- Data access
- Visualizations

# WebApp – Key Features

Some of the features we wanted the platform to have

- Near-real-time data visualisation
- Interactive map view of all sensors (public & private)
- Responsive design (works on phone, tablet, computer)
- Secure user accounts and data privacy
- Historical data, trends, and analytics
- Easy-to-Use

# System Architecture Overview


# System Architecture

- Web Dashboard: React - frontend
- API Server: FastAPI – backend
- MQTT Broker: Mosquitto - message queue


- Database: PostgreSQL + TimescaleDB for time series

Automated deployment with

- Hetzner
- GitHub workflows
- Docker Compose

# Tech Stack – frontend and backend


- Typescript & React
- Modern, fast, and maintainable web interface
- Reusable components
- Python & FastAPI
- High-performance backend
- Built-in API docs
- Clean separation
- Frontend <-> API via REST
- Easier scaling and updates

# Tech Stack – MQTT Mosquitto

- Lightweight protocol
- Ideal for small IoT devices
- Minimal bandwidth and power use
- Reliable messaging
- Real-time communication
- Low latency between sensors and cloud
- Support many devices simultaneously
- Open standard


- Works with ESPHome and other IoT systems

# Tech Stack – TimescaleDB


- Built on PostgreSQL
- Fast, reliable
- Industry standards, easy integration
- Time-series optimised
- Perfect for continuous sensor data
- Handles millions of rows efficiently
- Performance features
- Automatic data compression
- Fast aggregation over time windows
- Scalable & stable

# Tech Stack – DevOps


- Docker
- Isolated, portable services
- Consistent local and cloud setup
- GitHub Actions
- Automatic build, test, deploy
- Quick and safe releases
- Hetzner
- European servers
- High performance at low cost
- Self-Hosted
- Full control over data


# Security and Data Privacy


- Secured authentication using JWT tokens
- Encrypted connections (HTTPS, TLS)
- Each device has unique credentials
- Role-based access control

# WebApp – Getting Started

- New users can
- Navigate to dashboard.particularmatter.org
- Create an account
- Start adding locations, nodes, and sensors

# Locations & Sensors Management


- Locations
- Represent physical places (e.g. home, school, park)
- Group multiple devices under one area
- Store GPS coordinates, address, and metadata
- Nodes (Devices)
- Each Node = one physical device (ESP8266 or similar)
- Connects to Wi-Fi and sends data to the platform
- Identified by a unique registration code
- Sensors
- The actual measurement components attached to a node
- Examples: PM2.5, PM10, temperature, humidity, pressure
- Each sensor produces time-series data
- Easily configurable and replaceable

out

in

# Locations & Sensors Management


Forms to create and register locations, nodes, and sensors:

# WebApp – Main Dashboard & Map


- Explore and Visualise Data
- View all sensors at a glance on an interactive map (clustered or individual markers).
- See both your private locations’ data and all publicly available data.
- Click on a marker to open a popup with live sensor readings (e.g. PM2.5, temperature, humidity).
- Access Analytics Quickly
- From the map, navigate directly to a location or sensor’s detail page with historical charts.
- View aggregated air quality indicators (averages, AQI, etc.) for visible areas or selected devices.

# Recap for Users!

Web App; Create User; Location 1; Node 1; Node n; Build Device; Install Firmware; Power Up; Measurements; Database; To the Dashboard; *Application Output; *User Input

One Time Key

Access Dev. WiFi

Credential Check and Device Registration

# Use Cases & Applications


- Homeowners monitoring indoor air quality
- Schools evaluating classroom air quality
- Community groups measuring local pollution
- Researchers collecting environmental data
- Businesses assessing workspace environmental quality
- Farmers tracking greenhouse emissions

# Conclusions – a production-ready platform

This is a production-ready platform, not just a prototype

Areas of development:

- Backend API
- Frontend web application
- MQTT broker for IoT communication
- Database design and optimization
- Security implementation
- Deployment automation
- Testing infrastructure
- Documentation
- Hardware integration templates

# Thank You

Visit dashboard.particularmatter.org
Create an account
Order hardware (shopping list provided on git) Follow setup guide
Corresponding email: | Start monitoring! federico.dallo@cnr.it

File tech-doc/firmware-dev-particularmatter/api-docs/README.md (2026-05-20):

# API Documentation

All Web Portal APIs are served over HTTP/1.1. Once the device boots, they are accessible via the AP hotspot (default IP: `192.168.4.1`).

## Common Response Envelope

All responses are wrapped in the same outer structure. See [response-structure.md](./response-structure.md) for details.

```json
{
  "success": true,
  "data": {},
  "message": "",
  "timestamp": "yyyy/mm/dd HH:MM:SS"
}
```

> **Note:** The response examples in each endpoint document show only the contents of the `data` field.

---

## Endpoints

### System

| Method | Endpoint | Description |
| --- | --- | --- |
| GET | [/api/system/status](./endpoints/system-status.md) | Get device system status |
| POST | [/api/system/reboot](./endpoints/system-reboot.md) | Reboot the device |
| POST | [/api/system/reset](./endpoints/system-reset.md) | Factory reset (clears all saved settings) |
| POST | [/api/system/update-ap](./endpoints/system-update-ap.md) | Update AP hotspot SSID and password |
| GET | [/api/system/logs](./endpoints/system-logs.md) | Stream the on-device system log (plain text) |

### WiFi

| Method | Endpoint | Description |
| --- | --- | --- |
| POST | [/api/wifi/scan](./endpoints/wifi-scan.md) | Trigger a background WiFi scan |
| GET | [/api/wifi/ssid](./endpoints/wifi-ssid.md) | Poll for WiFi scan results |
| POST | [/api/wifi/save](./endpoints/wifi-save.md) | Save WiFi credentials and connect |

### Node

| Method | Endpoint | Description |
| --- | --- | --- |
| POST | [/api/node/save](./endpoints/node-save.md) | Pair the device using a one-time key |

---

## Measurements

| Method | Endpoint | Description |
| --- | --- | --- |
| GET | [/api/measurements](./endpoints/measurements-list.md) | List daily measurement CSV files on the SD card |
| GET | [/api/measurements/latest](./endpoints/measurements-latest.md) | Get the latest sensor snapshot with quality levels |
| GET | [/api/measurements/file](./endpoints/measurements-file.md) | Download a single daily measurement CSV file |
| GET | [/api/measurements/all](./endpoints/measurements-all.md) | Download all measurement files concatenated into one CSV |
| POST | [/api/measurements/delete](./endpoints/measurements-delete.md) | Delete a single daily measurement CSV file |

---

## Types & Enums

### Types

| Type | Description |
| --- | --- |
| [systemType](../types/systemType.md) | System status object |
| [wifiType](../types/wifiType.md) | WiFi status object |
| [nodeType](../types/nodeType.md) | Node pairing status object |
| [networkType](../types/networkType.md) | Single network entry from a WiFi scan |

### Enums

| Enum | Description |
| --- | --- |
| [CONNECTION_STATE](../enums/CONNECTION_STATE.md) | WiFi connection state values |
| [PAIRING_STATE](../enums/PAIRING_STATE.md) | Node pairing state values |

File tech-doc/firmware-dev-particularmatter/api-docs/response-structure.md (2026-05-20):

# API Response Structure

All API responses are wrapped in the following envelope.

```json
{
  "success": true,
  "data": {} | [],
  "message": "",
  "timestamp": "yyyy/mm/dd HH:MM:SS"
}
```

| Field | Type | Description |
| --- | --- | --- |
| `success` | Boolean | `true` on success, `false` on failure |
| `data` | Object \| Array | Endpoint-specific payload (see individual endpoint docs) |
| `message` | String | Error or informational message; empty string on success |
| `timestamp` | String | Device local time, format `yyyy/mm/dd HH:MM:SS` |

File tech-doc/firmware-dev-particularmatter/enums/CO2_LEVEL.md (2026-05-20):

# CO2_LEVEL

Quality level enum for the `co2` field in the [`/api/measurements/latest`](../api-docs/endpoints/measurements-latest.md) response.

Thresholds follow the **RESET Air** standard.

| Value | Color | ppm |
| --- | --- | --- |
| `GOOD` | 🟢 Green | < 600 |
| `MODERATE` | 🟡 Yellow | 600 – 999 |
| `POOR` | 🟠 Orange | 1000 – 1499 |
| `VERY_POOR` | 🔴 Red | ≥ 1500 |

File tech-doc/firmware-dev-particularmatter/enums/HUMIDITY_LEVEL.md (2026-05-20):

# HUMIDITY_LEVEL

Quality level enum for the `humidity` field in the [`/api/measurements/latest`](../api-docs/endpoints/measurements-latest.md) response.

Thresholds are based on **ASHRAE 55 / EN 15251**.

| Value | Color | %RH |
| --- | --- | --- |
| `DRY` | 🟠 Orange | < 30 |
| `COMFORTABLE` | 🟢 Green | 30 – 60 |
| `HUMID` | 🟡 Yellow | 61 – 80 |
| `VERY_HUMID` | 🔴 Red | > 80 |

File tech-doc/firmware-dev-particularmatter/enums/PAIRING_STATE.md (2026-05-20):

# PAIRING_STATE

Enum values for the `nodeType.pairingState` field.

| Value | Description |
| --- | --- |
| `UNREGISTERED` | Not yet paired (fresh boot or after a factory reset) |
| `REGISTERING` | Device is executing the HTTPS pairing request in the background |
| `REGISTERED` | Pairing successful; MQTT credentials have been obtained |
| `INVALID_KEY` | Server returned 400 / 401 / 403 (key invalid or expired) |
| `NETWORK_ERROR` | Server unreachable, timeout, or TLS failure |

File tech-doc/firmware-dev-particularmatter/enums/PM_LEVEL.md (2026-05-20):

# PM_LEVEL

Quality level enum for particulate matter fields (`pm1`, `pm25`, `pm10`) in the [`/api/measurements/latest`](../api-docs/endpoints/measurements-latest.md) response.

Thresholds follow the **Taiwan EPA AQI** breakpoints for PM2.5 and PM10. PM1 has no official standard and uses the PM2.5 breakpoints as a proxy.

| Value | Color | PM2.5 (µg/m³) | PM10 (µg/m³) |
| --- | --- | --- | --- |
| `GOOD` | 🟢 Green | 0 – 15.4 | 0 – 54 |
| `MODERATE` | 🟡 Yellow | 15.5 – 35.4 | 55 – 124 |
| `UNHEALTHY_SENSITIVE` | 🟠 Orange | 35.5 – 54.4 | 125 – 254 |
| `UNHEALTHY` | 🔴 Red | 54.5 – 150.4 | 255 – 354 |
| `VERY_UNHEALTHY` | 🟣 Purple | 150.5 – 250.4 | 355 – 424 |
| `HAZARDOUS` | 🟤 Brown | ≥ 250.5 | ≥ 425 |

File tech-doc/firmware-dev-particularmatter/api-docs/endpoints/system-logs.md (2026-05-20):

# GET /api/system/logs

Stream the in-memory system log ring buffer.

Unlike the rest of the API, this endpoint does **not** return a JSON envelope.
The body is the raw log lines as `text/plain`, transferred with
`Transfer-Encoding: chunked`. The firmware keeps the most recent **200**
lines in a fixed-size RAM ring buffer; this endpoint reads directly from
that buffer and does **not** touch the SD card, so it works even when no SD
card is inserted and never blocks on SD I/O.

The device also writes a longer history (up to ~2000 lines) to
`/log/system.log` on the SD card when one is present, but that file is not
served by this endpoint.

## Request

| Field | Value |
| --- | --- |
| URL | `/api/system/logs` |
| Method | GET |
| Content-Type | N/A |
| Auth | None |

No request body.

## Response

### Success — `200 OK`

| Header | Value |
| --- | --- |
| `Content-Type` | `text/plain; charset=utf-8` |
| `Content-Disposition` | `inline; filename="esp32_system.log"` |
| `Cache-Control` | `no-cache` |
| `Transfer-Encoding` | `chunked` |

Each line uses the format written by the firmware logger:

```
[+<ms> ms] [<LEVEL>] <message>
```

`<ms>` is `millis()` since boot (the device has no wall-clock source).
`<LEVEL>` is one of `I`, `W`, `E`, `D`.

#### Example body

```text
[+         0 ms] [I] Logger: file=/log/system.log lines=0 max=1000 buf=1024B interval=2000ms ring=200
[+       142 ms] [I] Web portal started at 192.168.4.1
[+      3050 ms] [W] LittleFS mount failed, attempting format...
[+      5210 ms] [I] API /system/status: received request
[+   1234567 ms] [E] SD write failed at /data/2026-05-13.csv
```

### Error — `503 Service Unavailable`

Returned only if the logger has not been initialized yet (should not happen
in normal operation). The body is plain text (no JSON envelope):

```text
Log unavailable: logger not started
```

## Notes

- Lines are served oldest → newest, in the order they were emitted.
- The ring buffer holds the most recent **200** lines; older history is
  discarded from RAM (but may still be on the SD card under
  `/log/system.log` / `/log/system.log.1`).
- Each `<message>` is truncated to **96 characters** when stored in the
  ring; the SD copy is not truncated.
- The ring buffer is **cleared on reboot** — only the SD copy survives a
  restart.
- Front-end clients should consume the body via `Response.text()` or stream
  it directly to a file download; do **not** attempt to parse it as JSON.

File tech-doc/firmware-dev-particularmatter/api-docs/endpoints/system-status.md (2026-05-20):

# GET /api/system/status

Returns the current system, WiFi, and node pairing status of the ESP32.

## Request

| Field | Value |
| --- | --- |
| URL | `/api/system/status` |
| Method | GET |
| Content-Type | N/A |
| Auth | None |

## Response (`data`)

| Field | Type | Description |
| --- | --- | --- |
| `systemStatus` | [systemType](../../types/systemType.md) | Firmware and AP information |
| `wifiStatus` | [wifiType](../../types/wifiType.md) | WiFi connection information |
| `nodeStatus` | [nodeType](../../types/nodeType.md) | Node pairing information |

### Response Example

```json
{
  "systemStatus": {
    "firmwareName": "ParticularMatter-Node",
    "firmwareVersion": "v2.0.0",
    "macAddress": "24:6F:28:AE:B1:0C",
    "isPasswordChanged": true,
    "firmwareSsid": "ESP-32 Setup",
    "allowedSkipInit": false,
  },
  "wifiStatus": {
    "ssid": "MyHomeNetwork_5G",
    "ipAddress": "192.168.1.150",
    "macAddress": "24:6F:28:AE:B1:0C",
    "rssi": -55,
    "connectionState": "CONNECTED"
  },
  "nodeStatus": {
    "nodeId": "a7f34d1b-25b2-4e9c-93b3-2ac9d8c7e218",
    "pairingState": "REGISTERED"
  }
}
```

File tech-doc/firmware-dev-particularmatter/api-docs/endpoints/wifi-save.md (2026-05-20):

# POST /api/wifi/save

Saves WiFi credentials and triggers a connection attempt. The device connects to the specified network in STA mode. Use [`GET /api/system/status`](./system-status.md) to monitor `connectionState` for the result.

## Request

| Field | Value |
| --- | --- |
| URL | `/api/wifi/save` |
| Method | POST |
| Content-Type | application/json |
| Auth | None |

### Request Body

| Field | Type | Required | Description |
| --- | --- | --- | --- |
| `ssid` | String | Yes | Target WiFi SSID |
| `password` | String | Yes | WiFi password; pass an empty string `""` for open networks |

### Request Example

```json
{
  "ssid": "MyHomeNetwork_5G",
  "password": "mysecretpassword"
}
```

## Response (`data`)

```json
{}
```

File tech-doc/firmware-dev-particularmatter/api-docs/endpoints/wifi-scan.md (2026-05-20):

# POST /api/wifi/scan

Triggers a background WiFi scan on the device.

After calling this endpoint, the client should start polling [`GET /api/wifi/ssid`](./wifi-ssid.md) every 2 seconds until `isFinished` is `true`.

## Request

| Field | Value |
| --- | --- |
| URL | `/api/wifi/scan` |
| Method | POST |
| Content-Type | application/json |
| Auth | None |

### Request Body

None.

## Response (`data`)

```json
{}
```

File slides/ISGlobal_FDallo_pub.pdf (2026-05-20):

# ISGlobal Seminar, 21 November 2025, Campus Mar - Barcelona

# Horizon EU HealthRiskADAPT: A focus on tool development to reduce indoor air pollution exposure. And why it matters

# Federico Dallo

# Introduction

# Who am I

## - Chemist - PhD in Environmental Science - Marie-Curie Postdoctoral Fellow - Researcher at ISP-CNR

# About what I’m doing

## - Tools for Environmental Monitoring - Modeling and Monitoring Indoors - → Health Impact Assessment (would like to learn…)

# Why I think this is relevant?

## - Identify the right approach to influence behavior toward building more resilient and sustainable societies in the context of climate change

# Outline

# Environmental Monitoring

## - Low-Cost Sensors - LCS Data Quality

# Built Environment and Wildfire Air Pollution

# - Wildfires – Case Study in CA - Modelling Infiltration of Outdoor PM2.5 Indoors - Reducing Indoor Exposure to PM2.5

# healthRiskADAPT project

# - Tools Development for Increasing Resilience to Climate Stressors

# Environmental Monitoring


## Increasing the maturity of measurements of essential climate variables (ECVs) at Italian atmospheric WMO/GAW observatories by implementing automated data elaboration chains. L Naitza, P Cristofanelli, A Marinoni, F Calzolari… - Computers & Geosciences, 2020

# Data Management


# Why Low-Cost Sensors?


# Assessing LCS Accuracy


## Calibration and assessment of electrochemical low-cost sensors in remote alpine harsh environments. F Dallo, D Zannoni, J Gabrieli, P Cristofanelli… -Atmospheric Measurement Techniques, 2021

UC Berkeley; CNR

# Built Environment and Wildfire Air Pollution

# Background

# Wildfires

# - Billion of dollars in annual losses in California - Main source of particulate matter in west

US

# Fine Particulate Matter (PM2.5)

# - Millions of premature death each year

# Climate Change

# - 27% increased risk of wildfire by 2050 relative to 2000 levels

Smoke from the 2018 Camp fire caused weeks of poor air quality in the San Francisco Bay area. Image: EPA

# Recap: why PM2.5 is a concern


FIGURE 6-2 Size and spatial complexity of particle deposition in different regions of the lung.
NOPL = nasal, oral, pharyngeal, and larynx. SOURCE: Nazaroff slide 7, adapted from Figure 1 in the cited publication.11 Comparisons of Calculated Respiratory Tract Deposition of Particles Based on the Proposed NCRP Model and the New ICRP66 Model. Yeh H-C, Cuddihy RG, Phalen RF, Chang IY. Aerosol Science and Technology 25(2):134–40. ©The American Association for Aerosol Research; http://www.tandfonline.com on behalf of The American Association for Aerosol Research, reprinted by permission of Taylor & Francis Ltd. National Academies of Sciences, Engineering, and Medicine. 2022. Indoor Exposure to Fine Particulate Matter and Practical Mitigation Approaches: Proceedings of a Workshop. Washington, DC: The National Academies Press. https://doi.org/10.17226/26331.

# How to reduce indoor exposure to wildfire PM2.5

# Best Practices

# - Shelter indoors: buildings are the first line of protection from PM2.5 exposure - Use a portable air cleaner (air purifier) - If you have one, use your mechanical air ventilation with high efficiency filter

# Barrier

# - Heavily dependent on occupants’ knowledge and behaviour


Smoke from the North Complex Fire settles over San Francisco. Image credits: Christopher Michel from Flickr)

# In short: what is an HVAC (~ VMC)

# Air Purifier Mechanical Air Ventilation

# Overview

# Objective

# - Study households HVAC usage during wildfires - Define HVAC best practices for reducing indoor exposure to wildfire PM2.5

# Approach

# - Use smart-thermostat open data to analyse HVAC runtime during wildfire days - Estimate the benefit of using a smart thermostat control logic to automatically run the HVAC during wildfire days


- Data from August to September 2020 | Hardware implementation for PM2.5 exposure reduction: • An Ecobee smart-thermostat on the left • Indoor PM2.5 monitor on the right

Fundings
- CITRIS and the Banatao Institute ($ 50k)
- Center for the Built Environment ($ 10k)
- EU Marie-Sklodowska Curie Action (https://cordis.europa.eu/project/id/844526)

# Smart thermostat data: fan runtime

# - 4,950 Ecobee smart thermostat, 159 NOAA monitors and 132 EPA stations - Daily median fan runtime: 5 hr 30 min - Wildfire day: 5 hr 18 min - Non-wildfire day: 5 hr 32 min - ~5% of houses do not use the HVAC at all

# Smart thermostat data: occupants’ behaviour


# - Manual interactions with the smart thermostats nearly double with a 10°C (18°F) increase in average outdoor temperature - There is no relationship between interactions with thermostat and outdoor PM2.5 - Households did not rely on HVAC during wildfire days to improve indoor air quality

# Model for estimating indoor PM2.5 concentration

# - We built a synthetic dataset of about 9,000 Californian homes using - The American Community Survey - ASHRAE Climate Zones

# Model for estimating indoor PM2.5 concentration


# Model for estimating indoor PM2.5 concentration

# - We modelled HVAC PM2.5 removal efficiency - Residential HVAC is as effective as about 4 air purifiers on average

# Potential benefit of using HVAC

# Sensitivity Analysis – Monte Carlo

# Additional 187.000 Simulations - House floor area


# - Effective leakage area of the

# building envelope - Initial indoor/outdoor (I/O)

# PM2.5 ratio (0.25, 0.50, 0.75) - Central air system filter efficiency (MERV 8, 10, 13, 16) - Central air system runtime

# (sampled using Sobol

# sequence)

# Health Impact Analysis

- The wildfire mode control strategy reduced mortality risk by 76%, with an estimated $29M in

# monetized benefits ($5 per month per household)

- The greatest potential to reduce the health impact of PM2.5 exposure lies in lower-income areas

### EPA’s BenMAP-CE software J.D. Sacks, J.M. Lloyd, Y. Zhu, J. Anderton, C.J. Jang, B. Hubbell, N. Fann, The Environmental Benefits Mapping and Analysis Program–Community Edition (BenMAP–

CE): A tool to estimate the health and economic benefits of reducing air pollution, Environ. Model. Softw. 104 (2018) 118–129.

concentration-response effect estimate

change in the incidence rate from the baseline

# Cluster Analysis

# - ~8 ug/m³ reduction near

# wildfires

# - ~5 ug/m³ reduction in the

# Central Valley (21% of the CA population) - ~3 ug/m³ reduction in the SF Bay Area - ~3 ug/m³ reduction in LA despite the distance from wildfires (urban air pollution?)

# Takeaways

- Sheltering indoors reduces exposure to outdoor PM2.5 levels by approximately 75% - Air conditioning reduces exposure to particulate matter by 40%, achieving indoor PM2.5 levels that are 87% lower than those outdoors - Wildfire mode reduces exposure to particulate matter by 54% or 90% compared to outdoor PM2.5 levels - Central air systems can match the filtration efficiency of 4 portable air purifiers in an average California home - Using wildfire mode increases system runtime by 46%, adding about $5 to monthly energy bills per California household

### Dallo, Federico, et al. "Using smart thermostats to reduce indoor exposure to wildfire fine particulate matter (PM2. 5)."

Indoor Environments (2025): 100088.

# https://github.com/CenterForTheBuiltEnvironment/tstat-wildfire

# Smart thermostat control logic

# Inputs


# - Occupancy - Outdoor PM2.5

# Optional

# - House characteristics - Floor Area - Age - Indoor PM2.5

# Output

# - Optimized HVAC fan runtime

Dallo et al. In Prep.

# Field Study

# Small Apartment

# - 48% of indoor PM2.5 reduction in

the period considered | Outdoor PM2.5 Indoor PM2.5 HVAC

# Detached House

# - 30% of indoor PM2.5 reduction in

the period considered | Outdoor PM2.5 Indoor PM2.5 HVAC

Dallo et al. In Prep.

# Conclusions

# Behaviour

# - Households were not using the HVAC system to reduce indoor PM2.5 concentration

# HVAC Performances

# - Equivalent to about 4 portable air cleaners - Up to 50% reduction in indoor exposure to

PM2.5

# Smart Thermostat Control Logic

# - Outdoor PM2.5 measurements can be used to automatic control of HVAC fan to reduce indoor PM2.5 exposure


A view of the San Francisco Bay on Nov. 14, 2018 (left) and three weeks prior. Image from Berkeley Lab, Kelly J. Owen.

UC Berkeley; CNR

# healthRiskADAPT project → Tools

11-2024 → 11-2028

# Resilience to Climate Stressors

# CNR

# Resilience to Climate Stressors


# Oslo Bern Lyon Naples*

# Can we disregard the indoor environments?

# - 90% of exposure to air pollution happens indoors - Infiltration of outdoor air pollution - Indoor activities (e.g., cooking, cleaning, … smoking) - The indoor environment is VERY complex


# - Building type (age, size, insulation, equipement installed, …) - Occupants (number, age, behaviour, …) - Location (climate, sources, built environments, …) - Indoor and outdoor sources of air pollution - Human Behaviour and Gender Dimension

- …

Exposure to Air Pollution: Largely Unknown, with Health Impacts Accounting for Only 10% of

# time spent outdoors → We need tools to measure indoor spaces

# Existing Methods…


## Dallo, Federico, et al. "Using smart thermostats to reduce indoor exposure

to wildfire fine particulate matter (PM2.

## 5)." Indoor Environments (2025):

100088.

## Martin, Andrew B., et al. "Investigating transport of particulate matter from cooking emissions in a multi-story house using low-cost sensor measurements and different modeling approaches." Indoor Environments

(2025): 100126.

## e.g., using Purple Air sensors

# Existing Monitoring Tools

# Non-Profit

# Source: npj Climate and Atmospheric Science | (2025)8:335

> 30k users,

## quite some interest!

# Private

# We Made Our Own Tool

## Contributors: Lorenzo Tenti and Alessandro Palo

# DIY Device - Hardware


# DIY Device - Firmware

# DIY Device - Registration


# Web App – Sensor Networks Configuration

# The Key Feature


# Locations & Sensors Management

# Web App - Main Dashboard


# healthRiskADAPT – Napoli as Case Study

# AQ and Building Data

# - estimate infiltration - estimate behaviour - estimate I/O ratio of PM2.5 - health impact

- …

# - Simulation and Interventions - Urban Green - Technical

### ENEA - forAIR-it

# Sources:

UNINA & UCCRN - Database GIS del centro studi PLINIVS per simulazioni su isola di calore urbana e consumi energetici a Napoli Est, include edifici e copertura del suolo parametrizzati per modellazioni climatiche ed energetiche, con output su griglia 125×125 m e scenari di ondate di calore (Tmrt) e consumi 2022.

# Spin-Off CNR - ParticularMatter


# Education

# Research

# Industry

## 2020 – Technical high-school project

# Final Thoughts…

# Why this is relevant also for remote areas? Cities: ~4% of EU landcover¹

# - 75% population → 85% by 2050² - Consumption > 65% of global energy³ - 70% CO2 emissions globally³ - → Environmental co-benefits are huge

# EU Missions: - Climate Resilience - Climate-Neutral Cities


### FIGURE 2-6 Output from a NASA model showing the different sources of particulate matter. Red = dust, blue = sea salt, green = smoke, and white = sulfate. SOURCE: Farmer slide 3 (NASA Center for Climate Simulation

at Goddard Space Flight Center).

### National Academies of Sciences, Engineering, and Medicine. 2022. Indoor Exposure to Fine Particulate Matter and Practical Mitigation Approaches: Proceedings of a Workshop. Washington, DC: The National Academies

Press. https://doi.org/10.17226/26331.

## 1Eurostat, ²EU Innovating cities, ³ Climate-Neutral and Smart Cities

## Spataro, Francesca, et al. "Tracing emerging contaminants in the Arctic cryosphere: Insights from Spitsbergen (Svalbard

Archipelago)." Journal of Hazardous Materials (2025): 140051.

# Recap

# Environmental Monitoring

## - Low-Cost Sensors - LCS Data Quality

# Built Environment and Air Pollution

# - Modelling Infiltration of Outdoor Air Pollutants Indoors - Reducing Indoor Exposure

# healthRiskADAPT project

# - Tools Development for Increasing Resilience to Climate Stressors Including Technological Interventions at Building Level

# - → Education (Gamification) → Identify the right approach to influence behavior toward building more resilient and sustainable societies in the context of climate change

Q&A

# Federico Dallo - federico.dallo@cnr.it

# Aknowledgements:

# Thomas Parkinson and Carlos Duarte

# & Lorenzo Tenti and Alessandro Palo

# & Naichen Zhao, Tuan-Vu, Chai Um, Ilaria

D’Elia, Massimo D’Isidoro, Mattia Leone,

# Cristina Visconti, Huy Zhang, Stefano

Schiavon, Chai Yoon Um, Mark Modera, Paul Raftery, Carlo Barbante, Brett C.

# Singer, Stefania Gilardoni, Giuseppe Antonelli, Giuliana Panieri…

# & Yocelyn Guerrero

# Thanks!

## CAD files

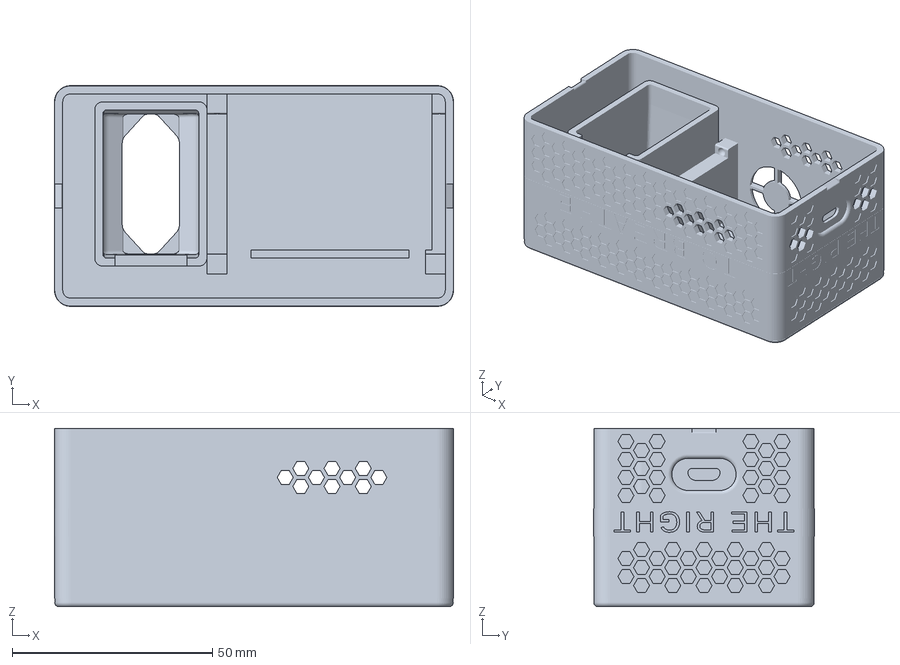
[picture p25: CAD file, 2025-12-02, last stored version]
src/3D_printer/generic_particulAir_1/generic_particulAir_body.3mf
99.6 x 55.1 x 44.5 mm

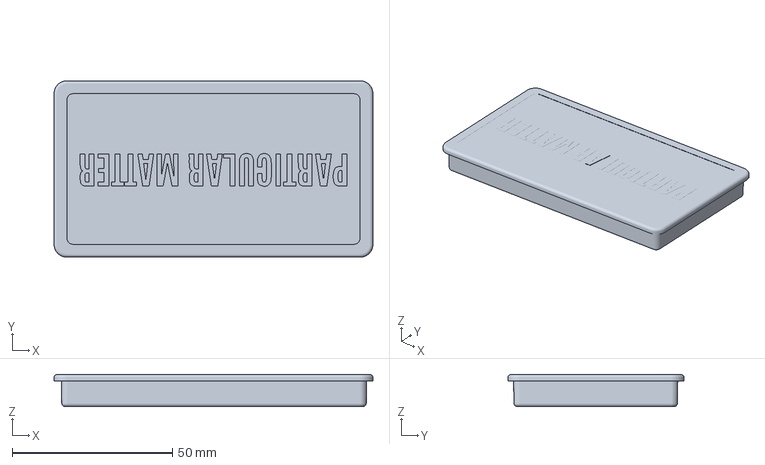
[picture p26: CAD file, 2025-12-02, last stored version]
src/3D_printer/generic_particulAir_1/generic_particulAir_cover.3mf
99.5 x 55.0 x 10.0 mm

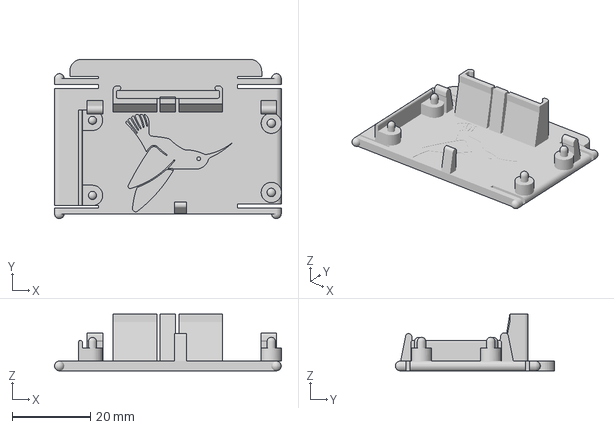
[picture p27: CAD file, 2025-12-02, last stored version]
src/3D_printer/generic_particulAir_1/generic_particulAir_electronics.3mf
58.1 x 40.8 x 14.5 mm

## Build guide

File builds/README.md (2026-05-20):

# Builds

This folder contains pre-built firmware, along with flashing instructions for each platform.

If you just want to flash the firmware without building from source, grab the binary from the corresponding subfolder and follow the instructions there.

## Platforms

| Folder | Platform |
|---|---|
| `esp32/` | ESP32 |
| `esp8266/` | ESP8266 |

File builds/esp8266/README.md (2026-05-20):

# ESP8266 Firmware — legacy

Pre-built firmware for ESP8266 device.

## Flashing Instructions - No command line

### ESPHome Web 

*add guidelines* for non expert for using [https://web.esphome.io/](https://web.esphome.io/)

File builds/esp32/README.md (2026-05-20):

# ESP32 Firmware — v1.4.0

Pre-built firmware for ESP32 device.

## Flashing Instructions - No command line

### ESPHome Web 

*add guidelines* for non expert for using [https://web.esphome.io/](https://web.esphome.io/)

## Flashing Instructions - Command line

### Install esptool
```
pip install esptool
```

### Find your serial port
- macOS / Linux: `ls /dev/tty.usb*`
- Windows: Device Manager → Ports (COM & LPT)

### Flash Command
Replace `PORT` with your actual serial port (e.g. `/dev/tty.usbserial-0001` on macOS, `COM3` on Windows):

```bash
esptool --chip esp32 --port PORT --baud 921600 write-flash 0x1000 v1.4.0.bin
```

### Notes
- Hold the BOOT button on the device before flashing, or ensure the device is in download mode <-- THIS IS NOT NECESSARY ON THE FEATHER ESP32 PLATFORM WE'RE USING
- If flashing fails, try a lower baud rate (e.g. `--baud 115200`)

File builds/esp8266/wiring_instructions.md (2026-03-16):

# Wiring Instructions

## Components

| Component | Description |
|---|---|
| **Adafruit Feather HUZZAH with ESP8266** | Main microcontroller board |
| **PMS5003** | PM2.5 Air Quality Sensor and Breadboard Adapter Kit |
| **Adafruit BME280** | I2C/SPI Temperature, Humidity, and Pressure Sensor (STEMMA QT) |
| **Senseair Sunrise CO2 sensor** | CO2 sensor (I2C), Senseair Sunrise series (TDE7318 / TDE5531) |

---

## Wiring

### Power

| Feather HUZZAH pin | Connects to |
|---|---|
| `USB` (5V) | `VCC` of PMS5003, `VIN` of BME280, `VBB` of Senseair Sunrise |
| `3V` (3.3V) | `VDDIO` of Senseair Sunrise |
| `GND` | `GND` of all sensors |

> The `USB` pin provides 5V when powered via USB. `VDDIO` on the Senseair Sunrise must be supplied at the I/O logic voltage of the host; use `3V` (3.3V) since all ESP8266 GPIOs operate at 3.3V.

---

### PMS5003 – PM2.5 Particle Sensor (UART)

Communication is one-way: only the TX line of the PMS5003 is read by the ESP8266.

| PMS5003 pin | Feather HUZZAH pin |
|---|---|
| `VCC` | `USB` (5V) |
| `GND` | `GND` |
| `TX` | `GPIO13` |

> `GPIO13` maps to the label **`MOSI`** on the Feather HUZZAH silkscreen.
> In firmware, configure a `SoftwareSerial` (or hardware Serial) listener on GPIO13.

---

### BME280 – Temperature / Humidity / Pressure Sensor (I2C)

| BME280 pin | Feather HUZZAH pin |
|---|---|
| `VIN` | `USB` (5V) |
| `GND` | `GND` |
| `SDA` | `SDA` (GPIO4) |
| `SCL` | `SCL` (GPIO5) |

> The **Adafruit BME280 STEMMA QT breakout includes 10 kΩ pull-up resistors on SDA and SCL**. These serve the entire I²C bus, including the Senseair Sunrise. No additional external pull-up resistors are required when using this specific breakout board.

---

### Senseair Sunrise – CO2 Sensor (I2C)

The Sunrise has additional control pins beyond the basic I2C lines. All must be connected correctly.

| Senseair Sunrise pin | Feather HUZZAH pin | Notes |
|---|---|---|
| `VBB` | `USB` (5V) | Main power supply |
| `VDDIO` | `3V` (3.3V) | I/O logic voltage — must match ESP8266 GPIO level |
| `GND` | `GND` | |
| `EN` | `USB` (5V) via 10kΩ pull-up | Drive HIGH for continuous operation; control via GPIO for low-power mode |
| `COMSEL` | `GND` | Selects I2C mode (leave floating or connect to GND) |
| `RXD/SDA` | `SDA` (GPIO4) | I2C data |
| `TXD/SCL` | `SCL` (GPIO5) | I2C clock |
| `nRDY` | optional GPIO | Active-low ready signal; can be left unconnected if using timing-based polling |

> **I2C address**: default is `0x68`. No conflict with the BME280 (default `0x76`/`0x77`).
>
> **Wake-up**: the Sunrise spends most of its time in deep sleep. Before any I2C read/write, the host must send the sensor's address to wake it up (START + address + STOP). The sensor will NACK this first byte if asleep, then ACK subsequent communication within 15 ms.

---

### I2C Pull-up Resistors

The Senseair Sunrise (TDE5531) includes only a 100 kΩ internal pull-up on SCL and **no internal pull-up on SDA**. The I²C specification and TDE5531 require the SDA line to be pulled up externally. TDE5531 recommends a pull-up range of **5 kΩ–15 kΩ** on both lines for reliable operation at 100 kbit/s (standard mode).

The ESP8266's internal pull-ups (configurable via software) are **not sufficient**: they are in the range of 30 kΩ–100 kΩ, far above the 15 kΩ maximum recommended by the Senseair datasheet. Using them would result in slow signal rise times and likely communication failures with the Sunrise.

**When using the Adafruit BME280 STEMMA QT breakout, no additional external resistors are needed.** The Adafruit BME280 breakout includes **10 kΩ pull-up resistors on both SDA and SCL** as part of its on-board circuitry. Since all I²C devices share the same bus lines, these pull-ups apply to the Sunrise as well. 10 kΩ falls within the 5 kΩ–15 kΩ recommended range, satisfying the Senseair requirement.

If the BME280 breakout is replaced with a bare chip or a different module that does not include on-board pull-ups, add external 10 kΩ resistors:

| Line | Pull-up resistor | Connected between |
|---|---|---|
| `SDA` (GPIO4) | 10 kΩ | `SDA` and `3V` (3.3V) |
| `SCL` (GPIO5) | 10 kΩ | `SCL` and `3V` (3.3V) |

---

## Summary Diagram

```
Feather HUZZAH ESP8266
┌──────────────────────────┐
│                          │
│  USB (5V) ───────────────┼──── VCC  (PMS5003)
│                     ─────┼──── VIN  (BME280)
│                     ─────┼──── VBB  (Senseair Sunrise)
│                     ─────┼──── EN   (Senseair Sunrise, via 10kΩ to VBB)
│                          │
│  3V (3.3V) ──────────────┼──── VDDIO (Senseair Sunrise)
│                          │
│  GND ────────────────────┼──── GND    (PMS5003)
│                     ─────┼──── GND    (BME280)
│                     ─────┼──── GND    (Senseair Sunrise)
│                     ─────┼──── COMSEL (Senseair Sunrise) → selects I2C
│                          │
│  GPIO13 (MOSI) ──────────┼──── TX     (PMS5003)
│                          │
│  SDA (GPIO4) ────────────┼──── SDA    (BME280)
│                     ─────┼──── RXD/SDA (Senseair Sunrise)
│                          │
│  SCL (GPIO5) ────────────┼──── SCL    (BME280)
│                     ─────┼──── TXD/SCL (Senseair Sunrise)
│                          │
└──────────────────────────┘
```

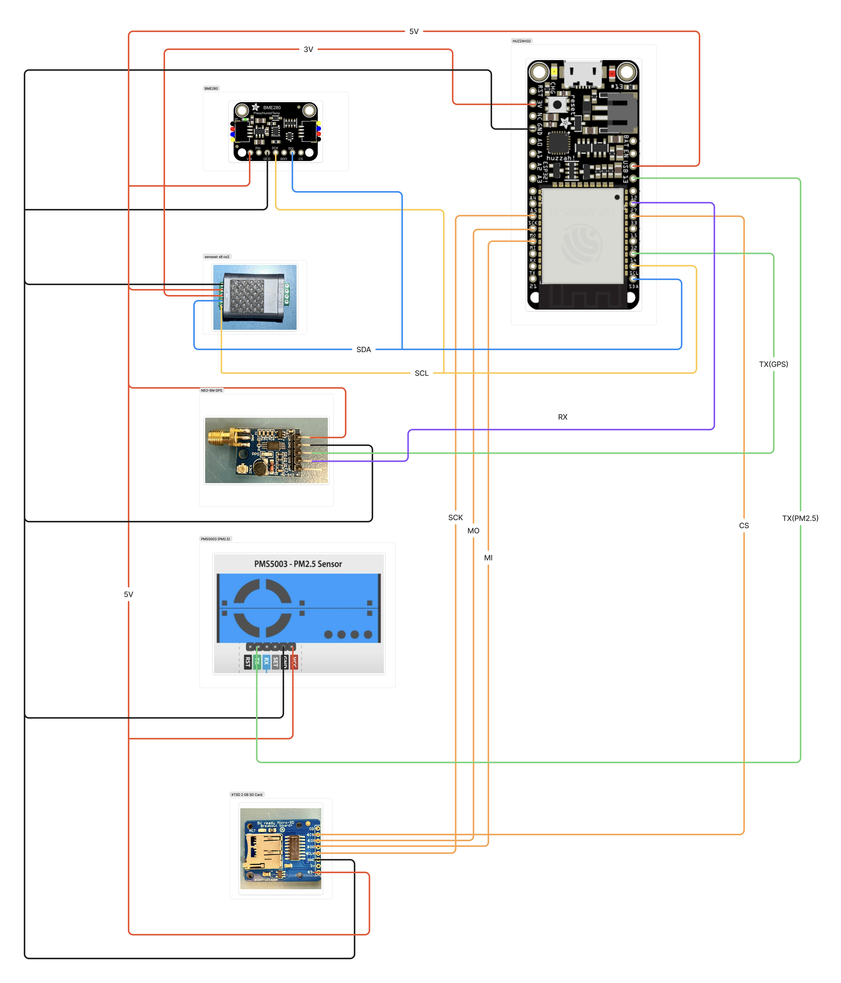
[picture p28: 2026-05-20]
tech-doc/firmware-dev-particularmatter/wirings/wiring.jpeg

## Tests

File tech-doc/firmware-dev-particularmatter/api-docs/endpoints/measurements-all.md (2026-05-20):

# GET /api/measurements/all

Downloads every daily measurement CSV file on the SD card, concatenated into a single CSV. The canonical header is emitted once at the top and the per-file header lines are stripped from each subsequent file, so the output is a valid single CSV that contains every row across all days.

Like [`GET /api/measurements/file`](./measurements-file.md), this endpoint does **not** return a JSON envelope: the body is raw `text/csv` streamed with `Transfer-Encoding: chunked`.

## Request

| Field | Value |
| --- | --- |
| URL | `/api/measurements/all` |
| Method | GET |
| Content-Type | N/A |
| Auth | None |

### Request Body

None.

## Response

### Success — `200 OK`

| Header | Value |
| --- | --- |
| `Content-Type` | `text/csv; charset=utf-8` |
| `Content-Disposition` | `attachment; filename="measurements_all.csv"` |
| `Cache-Control` | `no-cache` |
| `Transfer-Encoding` | `chunked` |

Files are emitted in filename order, which — given the `YYYY-MM-DD` prefix — is chronological ascending. Every row already carries its own `gps_datetime` / `wifi_datetime`, so no per-file separator is needed.

#### Example body

```csv
gps_datetime,wifi_datetime,ts_ms,pm1,pm25,pm10,co2,temperature,humidity,pressure,lat,lng,altitude,hdop,satellites,gps_valid
2026-05-11T03:59:50Z,2026-05-11T03:59:50Z,1000,4,7,11,415,26.10,57.80,1012.50,25.034000,121.564000,12.1,0.90,9,1
2026-05-11T04:00:00Z,2026-05-11T04:00:00Z,11200,5,7,12,416,26.12,57.82,1012.49,25.034000,121.564000,12.1,0.90,9,1
2026-05-12T04:00:01Z,2026-05-12T04:00:01Z,12345,5,8,12,420,26.31,58.12,1012.45,25.034012,121.564021,12.3,0.90,9,1
2026-05-13T04:00:01Z,2026-05-13T04:00:01Z,12345,6,9,13,418,26.34,58.05,1012.43,25.034000,121.564000,12.4,0.90,9,1
```

If no measurement files exist, the response is still `200 OK` and contains only the header line.

## Errors

Errors use the standard JSON envelope.

| HTTP | `message` | Cause |
| --- | --- | --- |
| 503 | `SD card not ready` | SD card unavailable or not mounted |

> **Note:** The device pauses sensor sampling and MQTT publishing for the duration of the transfer (the HTTP server runs on the main loop). For deployments with many days of accumulated data, prefer per-file downloads via [`/api/measurements/file`](./measurements-file.md) so each transfer completes quickly and is independently retryable.

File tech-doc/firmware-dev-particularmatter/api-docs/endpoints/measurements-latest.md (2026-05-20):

# GET /api/measurements/latest

Returns the most recent sensor snapshot collected by the device — one entry per sensor field, including its current value, unit, the number of samples aggregated in the last MQTT interval for that sensor group, and a quality level string.

Because each sensor driver polls hardware at its own rate (e.g. PMS5003 every 3 s, BME280 every 2 s), the `samplesInInterval` value can differ between sensor groups within the same MQTT interval.

## Request

| Field | Value |
| --- | --- |
| URL | `/api/measurements/latest` |
| Method | GET |
| Content-Type | N/A |
| Auth | None |

### Request Body

None.

---

## Response (`data`)

### Top-level fields

| Field | Type | Description |
| --- | --- | --- |
| `mqttIntervalMs` | Number | MQTT publish interval in milliseconds (e.g. `1000`) |
| `pm1` | [SensorField](#sensorfield-object) | PM1.0 particulate matter |
| `pm25` | [SensorField](#sensorfield-object) | PM2.5 particulate matter |
| `pm10` | [SensorField](#sensorfield-object) | PM10 particulate matter |
| `co2` | [SensorField](#sensorfield-object) | CO₂ concentration |
| `temperature` | [SensorField](#sensorfield-object) | Ambient temperature |
| `humidity` | [SensorField](#sensorfield-object) | Relative humidity |
| `pressure` | [SensorField](#sensorfield-object) | Atmospheric pressure (no `level`, always `null`) |

### `SensorField` object

| Field | Type | Description |
| --- | --- | --- |
| `value` | Number \| `null` | Sensor reading. `null` when `valid` is `false` |
| `unit` | String | Physical unit of the value (see table below) |
| `valid` | Boolean | `true` if the sensor produced a valid reading in the last interval |
| `samplesInInterval` | Number | Number of hardware polls that were successfully aggregated by this sensor's driver in the last MQTT interval. Shared across fields that belong to the same physical sensor (pm1/pm25/pm10 share one count; co2 has its own; temperature/humidity/pressure share one) |
| `level` | [PM_LEVEL](../../enums/PM_LEVEL.md) \| [CO2_LEVEL](../../enums/CO2_LEVEL.md) \| [TEMPERATURE_LEVEL](../../enums/TEMPERATURE_LEVEL.md) \| [HUMIDITY_LEVEL](../../enums/HUMIDITY_LEVEL.md) \| `null` | Quality level enum value derived from the reading. `null` when `valid` is `false` or the field has no defined threshold (`pressure`). See the enum reference table below for which enum applies to each field |

#### Units per field

| Field | Unit |
| --- | --- |
| `pm1`, `pm25`, `pm10` | `µg/m³` |
| `co2` | `ppm` |
| `temperature` | `°C` |
| `humidity` | `%RH` |
| `pressure` | `hPa` |

---

## Level enums

| Field | Enum | Reference |
| --- | --- | --- |
| `pm1`, `pm25`, `pm10` | [PM_LEVEL](../../enums/PM_LEVEL.md) | Taiwan EPA AQI; PM1 uses PM2.5 breakpoints as proxy |
| `co2` | [CO2_LEVEL](../../enums/CO2_LEVEL.md) | RESET Air standard |
| `temperature` | [TEMPERATURE_LEVEL](../../enums/TEMPERATURE_LEVEL.md) | ASHRAE 55 comfort zone |
| `humidity` | [HUMIDITY_LEVEL](../../enums/HUMIDITY_LEVEL.md) | ASHRAE 55 / EN 15251 |
| `pressure` | — | No threshold defined; `level` is always `null` |

---

## Response Example

```json
{
  "mqttIntervalMs": 10000,
  "pm1":         { "value": 4,       "unit": "µg/m³", "valid": true,  "samplesInInterval": 3, "level": "GOOD" },
  "pm25":        { "value": 7,       "unit": "µg/m³", "valid": true,  "samplesInInterval": 3, "level": "GOOD" },
  "pm10":        { "value": 11,      "unit": "µg/m³", "valid": true,  "samplesInInterval": 3, "level": "GOOD" },
  "co2":         { "value": 415,     "unit": "ppm",   "valid": true,  "samplesInInterval": 3, "level": "GOOD" },
  "temperature": { "value": 26.10,   "unit": "°C",    "valid": true,  "samplesInInterval": 5, "level": "COMFORTABLE" },
  "humidity":    { "value": 57.80,   "unit": "%RH",   "valid": true,  "samplesInInterval": 5, "level": "COMFORTABLE" },
  "pressure":    { "value": 1012.50, "unit": "hPa",   "valid": true,  "samplesInInterval": 5, "level": null }
}
```

### When sensors are not yet ready

If the device has just booted and no valid reading has been collected yet, all `SensorField` entries will have `valid: false`, `value: null`, `samplesInInterval: 0`, and `level: null`.

```json
{
  "mqttIntervalMs": 10000,
  "pm1":         { "value": null, "unit": "µg/m³", "valid": false, "samplesInInterval": 0, "level": null },
  "pm25":        { "value": null, "unit": "µg/m³", "valid": false, "samplesInInterval": 0, "level": null },
  "pm10":        { "value": null, "unit": "µg/m³", "valid": false, "samplesInInterval": 0, "level": null },
  "co2":         { "value": null, "unit": "ppm",   "valid": false, "samplesInInterval": 0, "level": null },
  "temperature": { "value": null, "unit": "°C",    "valid": false, "samplesInInterval": 0, "level": null },
  "humidity":    { "value": null, "unit": "%RH",   "valid": false, "samplesInInterval": 0, "level": null },
  "pressure":    { "value": null, "unit": "hPa",   "valid": false, "samplesInInterval": 0, "level": null }
}
```

---

## Errors

| HTTP | `message` | Cause |
| --- | --- | --- |
| 503 | `Sensor system not initialised` | Called before the sensor loop has run at least once |

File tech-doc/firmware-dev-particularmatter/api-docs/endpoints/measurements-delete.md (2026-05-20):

# POST /api/measurement/delete

Deletes a single daily measurement CSV file from the SD card by filename.

Use [`GET /api/measurements`](./measurements-list.md) to obtain the list of available filenames before calling this endpoint.

## Request

| Field | Value |
| --- | --- |
| URL | `/api/measurement/delete` |
| Method | POST |
| Content-Type | `application/json` |
| Auth | None |

### Request Body

| Field | Type | Required | Description |
| --- | --- | --- | --- |
| `name` | String | Yes | Filename of the measurement file to delete (e.g. `2026-05-11_log.csv`) |

### Request Example

```json
{
  "name": "2026-05-11_log.csv"
}
```

## Response (`data`)

```json
{}
```

## Errors

| HTTP | `message` | Cause |
| --- | --- | --- |
| 400 | `Missing field: name` | The `name` field was not provided in the request body |
| 404 | `File not found` | No file with the given name exists on the SD card |
| 503 | `SD card not ready` | SD card unavailable or not mounted |

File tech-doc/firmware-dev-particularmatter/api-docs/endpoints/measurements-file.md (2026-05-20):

# GET /api/measurements/file

Downloads a single daily measurement CSV file from the SD card.

Unlike most endpoints, this one does **not** return a JSON envelope: the body is the raw CSV file streamed as `text/csv` with `Transfer-Encoding: chunked` so the firmware never loads the whole file into RAM.

## Request

| Field | Value |
| --- | --- |
| URL | `/api/measurements/file` |
| Method | GET |
| Content-Type | N/A |
| Auth | None |

### Query parameters

| Field | Type | Required | Description |
| --- | --- | --- | --- |
| `name` | String | Yes | Filename to download. Must match the pattern `YYYY-MM-DD_log.csv` (the names returned by [`GET /api/measurements`](./measurements-list.md)). |

### Example request

```
GET /api/measurements/file?name=2026-05-13_log.csv
```

## Response

### Success — `200 OK`

| Header | Value |
| --- | --- |
| `Content-Type` | `text/csv; charset=utf-8` |
| `Content-Disposition` | `attachment; filename="<name>"` |
| `Cache-Control` | `no-cache` |
| `Transfer-Encoding` | `chunked` |

The body is the verbatim CSV file. The first line is the canonical header; every subsequent line is one measurement row.

#### Example body

```csv
gps_datetime,wifi_datetime,ts_ms,pm1,pm25,pm10,co2,temperature,humidity,pressure,lat,lng,altitude,hdop,satellites,gps_valid
2026-05-13T04:00:01Z,2026-05-13T04:00:01Z,12345,5,8,12,420,26.31,58.12,1012.45,25.034000,121.564000,12.3,0.90,9,1
2026-05-13T04:00:11Z,2026-05-13T04:00:11Z,22468,6,9,13,418,26.34,58.05,1012.43,25.034012,121.564021,12.4,0.90,9,1
```

## Errors

Errors use the standard JSON envelope.

| HTTP | `message` | Cause |
| --- | --- | --- |
| 400 | `Missing 'name' query parameter` | `name` was not supplied |
| 400 | `Invalid filename` | `name` does not match `YYYY-MM-DD_log.csv` |
| 404 | `File not found` | File does not exist on the SD card |
| 500 | `Failed to open file` | SD I/O error while opening the file |
| 503 | `SD card not ready` | SD card unavailable or not mounted |

> **Security note:** Only filenames that match the strict pattern `YYYY-MM-DD_log.csv` are accepted; any other input (including paths containing `/` or `..`) returns `400` without touching the filesystem.

> **Note:** The device pauses sensor sampling and MQTT publishing for the duration of the transfer (the HTTP server runs on the main loop). Large downloads complete in seconds over the AP — keep this in mind for the UI.

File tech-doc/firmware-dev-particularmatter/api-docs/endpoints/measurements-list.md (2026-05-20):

# GET /api/measurements

Returns the list of daily measurement CSV files currently stored on the SD card under `/measurements/`.

Use this endpoint to populate a download UI (e.g. a list of dates with file sizes). To actually fetch a file, call [`GET /api/measurements/file`](./measurements-file.md). To download every file as a single concatenated CSV, call [`GET /api/measurements/all`](./measurements-all.md).

## Request

| Field | Value |
| --- | --- |
| URL | `/api/measurements` |
| Method | GET |
| Content-Type | N/A |
| Auth | None |

### Request Body

None.

## Response (`data`)

| Field | Type | Description |
| --- | --- | --- |
| `count` | Number | Number of measurement files available |
| `totalBytes` | Number | Sum of all file sizes in bytes |
| `files` | Array(Object) | Per-file metadata (see below) |

### `files[]` item

| Field | Type | Description |
| --- | --- | --- |
| `name` | String | Filename, format `YYYY-MM-DD_log.csv` |
| `size` | Number | File size in bytes |
| `date` | String | ISO date extracted from the filename (`YYYY-MM-DD`) |

### Response Example

```json
{
  "count": 3,
  "totalBytes": 912345,
  "files": [
    { "name": "2026-05-11_log.csv", "size": 287010, "date": "2026-05-11" },
    { "name": "2026-05-12_log.csv", "size": 312456, "date": "2026-05-12" },
    { "name": "2026-05-13_log.csv", "size": 312879, "date": "2026-05-13" }
  ]
}
```

> **Note:** Files are sorted by filename, which — given the `YYYY-MM-DD` prefix — is equivalent to chronological order ascending.

## Errors

| HTTP | `message` | Cause |
| --- | --- | --- |
| 503 | `SD card not ready` | SD card unavailable or not mounted |

When the `/measurements/` directory does not exist yet (no measurement has ever been written), the endpoint still returns `200` with `count: 0` and an empty `files` array.

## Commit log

2025-11-07 feat: adding BOM
2025-11-07 feat: some corrections on BOM
2025-11-08 fix: adding hyperlink to the STL file for the Particular Matter Device
2025-11-08 feat: adding bom path in readme
2025-12-02 feat: adding generic 3D printer files for the enclosure
    [generic_particulAir_body.3mf, generic_particulAir_cover.3mf, generic_particulAir_electronics.3mf]
2025-12-18 feat: dissemination material ISGlobal presentation
2026-03-16 feat: add wiring instructions and project configuration files
2026-03-16 fix: remove unnecessary wiring instructions HTML file and update .gitignore
2026-03-16 fix: add sensor datasheets directory to .gitignore
2026-03-16 feat: update wiring instructions for Senseair Sunrise CO2 sensor integration
2026-03-16 feat: update Bill of Materials to include Senseair Sunrise CO2 sensor and pricing details
2026-05-02 feat: update README structure and add seminar presentation materials
2026-05-20 refactor: update the structure of the repo (esp32-release)
2026-05-20 refactor: remove the compiled files and useless materials (esp32-release)
    [generic_particulAir_body.3mf, generic_particulAir_cover.3mf, generic_particulAir_electronics.3mf]
2026-05-20 docs: rewrite and align all README files for esp32-release
    - Rewrite root README to reflect ESP32 platform, actual repo structure, GPL v3 license
    - Add slides/README.md with file listing
    - Update builds/README.md with platform table
    - Update builds/esp32/README.md with descriptive title
    - Update tech-doc/README.md with welcoming intro
2026-05-20 refactor: update the name of project (esp32-release)
2026-05-20 Enhance README with ESP8266 and sensor information
    Updated README to include details about ESP8266 support and additional sensors.
2026-05-20 Update README with flashing instructions and guidelines
    Added guidelines for non-experts using ESPHome Web and clarified flashing instructions for the Feather ESP32 platform.
2026-05-20 Update README with ESP32 flashing instructions
    Removed unnecessary flashing instructions for Feather ESP32 platform and added guidelines for using ESPHome.
2026-05-20 Add wiring instructions for ESP8266 and sensors
    Added detailed wiring instructions for connecting the Adafruit Feather HUZZAH with ESP8266 to various sensors including PMS5003, BME280, and Senseair Sunrise CO2 sensor.
